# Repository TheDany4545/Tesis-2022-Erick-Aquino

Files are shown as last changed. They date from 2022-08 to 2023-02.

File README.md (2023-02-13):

# Estimulador nervio vago y su varilla programadora 2022
En este respositorio se encuentra la combinación de los avances previos a la Fase IV. En esta fase se logró crear un modo de reconocimiento automático. Además de la creación de PCB para la varilla programadora.

## Modo automático
Es basado en el modo de funcionamiento de *detección y respuesta* también conocido como *AutoStim* de los modelos LivaNova 106 y 1000. Consiste en emplear un sistema de monitoreo y recolección de información de impulsos eléctricos de la actividad cardíaca mediante un electrocardiograma (ECG). La administración de la dosis para la terapia se activa de forma automática al momento de detectar un aumento rápido en la frecuencia cardíaca, la cual es asociada a las convulsiones.

<p align="center">
  
</p>

### Documentación
Se encuentran artículos cientificos, datasheets de distintos componentes y microcontroladores, pinouts y base de datos en formato .csv para hacer las pruebas.

### Estimulador
Carpeta donde se encuentra los códigos de los microcontroladores ESP8266 y Trinket M0 para la estimulación VNS y la recepción de parámetros. También se encuntran los diseños de PCB's de distintos años.

### Recursos
Carpeta donde se encuentra la librería PyHRV modificada para la obtención de resultados en el análisis de los ECG´s. También se encuentra una herramienta de Matlab obtenida desde Physionet para la simulación de un ECG donde uno pude modificar parámetros de simulación. Se agregó un archivo .txt con un link para descargar todas las librerias y se describe la instalación en anaconda.

### Varilla Programadora
En la varilla programadora se tiene el envio de parámetros el cual es modificable a través de una interfaz gráfica la cual se ejecuta desde python y esto lo hace a través del microcontrolador ESP8266 al cual se le carga un programa en C que permite la comunicación entre la interfaz gráfica y el estimualdor por medio del envio de parámetros a través del NRFL24L01.

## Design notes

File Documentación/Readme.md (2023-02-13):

## Artículo científico
Artículo científico del cual se basó para la obtención de features de un electrocardiograma con enfoque a convulsiones en orden de poder predecir una convulsión antes de que ocurra con dichos features.

## Base de datos
Base de datos de electrocardiogramas haciendo actividad física a 500 Hz, sin filtrar.

## Esquemáticos
En esta carpeta se encuentran los Pinouts de los microcontroladores ESP8266, Trinket M0.

## Esquemas Fritzing
En esta carpeta se encuentran las conexiones de como es el cableado de Raspberry Pi4 con TTL, cableado de ESP8266 con NRF24L01 y pantalla LCD y cableado de Trinket M0 con NRF24L01. Todos los circuitos mencionados cableados en una simulación en el programa Fritzing.

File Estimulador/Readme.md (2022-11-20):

## Estimulador VNS
### Codigos microcontroladores
En esta carpeta se encuentra los códigos para usar con Trinket M0 y ESP8266. El trinket M0 conectado al NRFL24L01 tiene comunicación con el otro NRFL24L01 conectado al ESP8266, de esta manera se puede enviar y recibir los parámetros de estimulación.
### PCB´s
En esta carperta se encuentran archivos de texto con links para los distintos PCB´s de distintos años. Estos links son de google drive, se descargan los archivos y se abren con Altium Designer. La versión utilizada de Altium Designer es 19.0.15.

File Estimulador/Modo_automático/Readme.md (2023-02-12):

## Send_data
Programa para enviar por medio de comunicación serial el archivo de ECG seleccionado.
### Enable ttS0
Linea de código para ser ejecutada en CMD de RaspBerry Pi4 para habilitar puerto serial.

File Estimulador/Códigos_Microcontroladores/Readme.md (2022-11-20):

## Códigos para envio y recepción de parámetros
### Trinket M0
En esta carpeta se encuentra el código para recibir parámetros con el trinket M0 conectado a un NRF24L01. Se abre con ide de arduino.
### Estimulador_final
En esta carpeta se encuentra el código para enviar parámetros a través de ESP8266 conectado a un NRF24L01. Se abre con ide de arduino.

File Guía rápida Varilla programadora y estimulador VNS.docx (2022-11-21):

# Guía rápida Varilla programadora y estimulador VNS

## Instalación de librerías para enviroment de anaconda

- Instale Python 3.X
- Después de descargar anaconda se debe crear un enviroment nuevo como se muestra en al Figura No.1

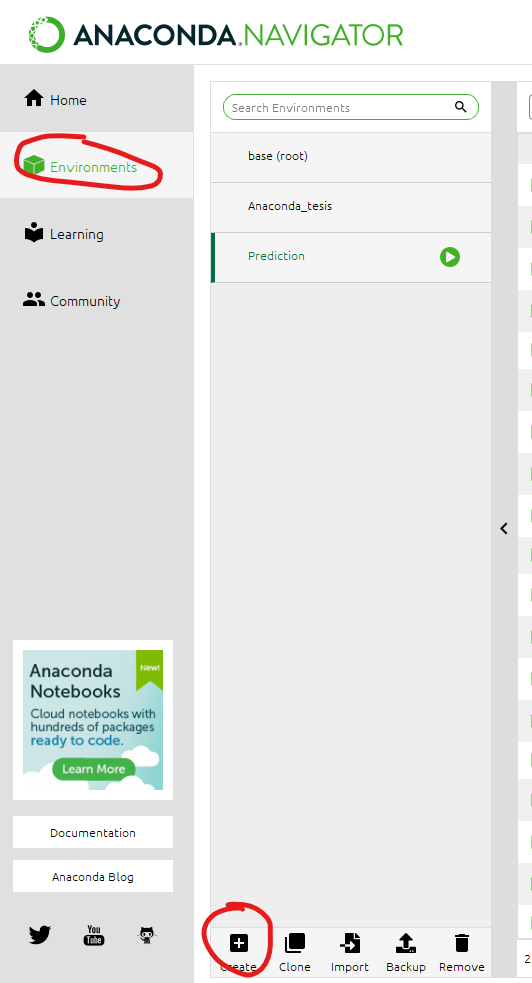
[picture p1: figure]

Figura No.1 – Creación de un nuevo enviroment

- Se instala spyder en el enviroment creado
- Para instalar el paquete de librerías “PyHRV” el cual da más conflictos es necesario seguir los siguientes pasos.
  - Desde el cmd ejecutar el siguiente comando “pip install pyhrv”
  - Si tiene error en la instalación con la librería specturm haga lo siguiente: Busque en su navegador Unofficial Windows Binaries for Python Extension Packages y busque el archivo. whl de spectrum. Descarguelo, si no encuentra uno, puede probar con el que se usó para resolver este problema (link (https://drive.google.com/file/d/1RalWyMJzHLhGzzO3uuIBB_u6xB2uzpj_/view?usp=share_link)).
  - Una vez descargado este archivo ejecute el comando “pip install path_del_archivo_whl”
  - Luego diríjase a la página oficial de Pyhrv (link (https://pypi.org/project/pyhrv/)) y desargue el archivo .whl para Python 3 o py3 como se ve en la figura No.2   Figura No.2 – archivo de Pyhrv.whl

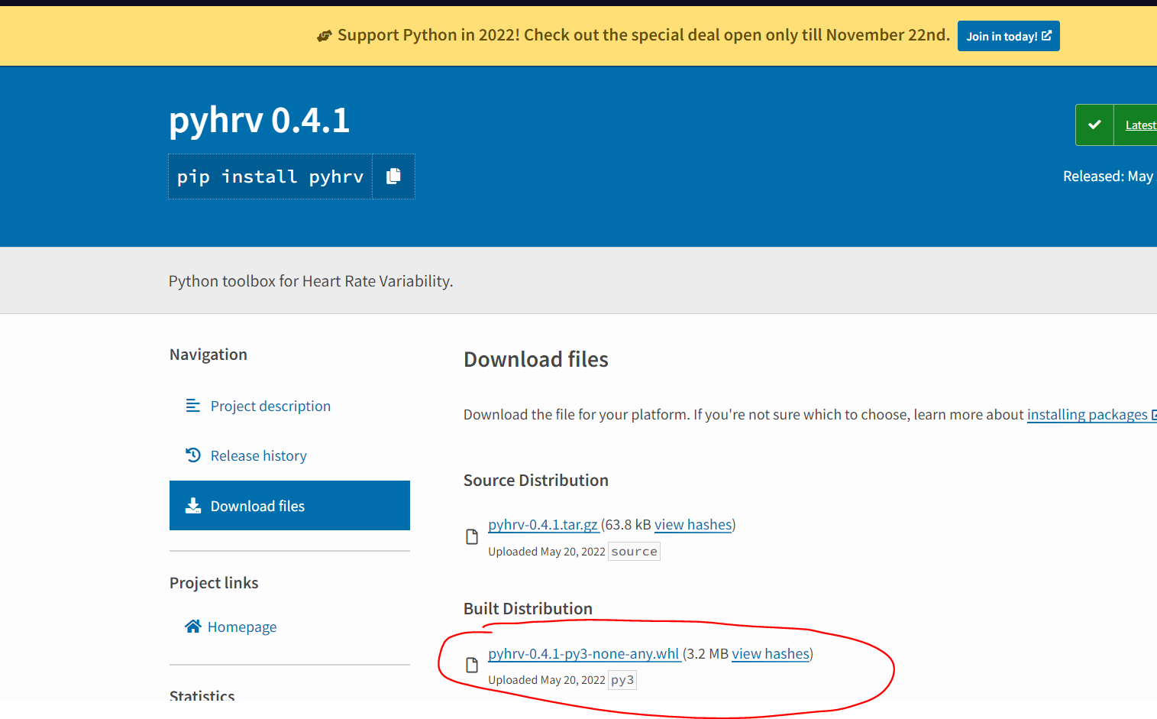
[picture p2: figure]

  - Una vez descargado desde el cmd ejecute el siguiente comando “pip install install path_del_archivo_whl ”
  - Puede probar con la versión utilizada para esta fase en el siguiente enlace (link (https://drive.google.com/file/d/1hLOSCwM4K9Iysz15rCaWuRM_AKxwgxKs/view?usp=share_link)).
  - Luego de haber instalado pyhrv traslade el conjunto de librerías instaladas hacia el enviroment de anaconda.
  - Para esto vaya a la ubicación de Python, ya en la carpeta busque la carpeta que se llame Lib>site-packages y luego copie las librerías instaladas. En mi caso la ruta es la siguiente: “C:\Users\eaqui\AppData\Local\Programs\Python\Python310\Lib\site-packages”
  - Luego de copiarlas diríjase a la la ubicación de Anaconda, ya en la ubicación dirigase a “envs>nombre_de_su_enviroment>Lib>site-packages” y pegue en esta ubicación las librerías. En mi caso esta ruta es “C:\Users\eaqui\.conda\envs\Prediction\Lib\site-packages”
- En caso de que no haya funcionado descargue directamente mi carpeta de “site-pacakges” que se encuentra en Google drive (link (https://drive.google.com/file/d/1yRFfxajOZiTD5mbhZKM890OWoaXSG9Wl/view?usp=share_link)) y reemplaze la carpeta por la que tiene en el directorio de anaconda “envs>nombre_de_su_enviroment>Lib>site-packages”.
- Ahora puede abrir anaconda en su enviroment y ejecute Spyder, abra el archivo llamado “ECG_Poincare.py”.
- Antes de ejecutar el archivo dirigase a PYTHONPATH manager y agrege un nuevo path como se muestra en la Figura No.3

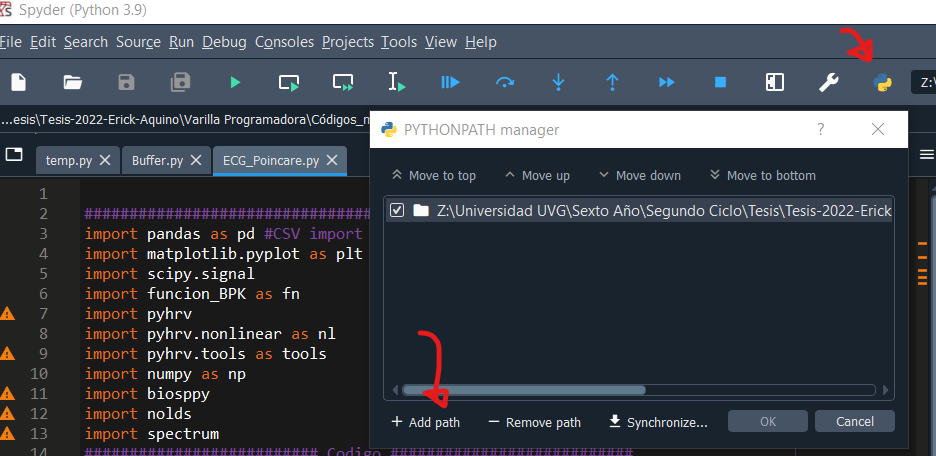
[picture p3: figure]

Figura No.3 – PYTHONPATH manager

- Busque la carpeta donde se encuentre el archivo “funcion_BPK.py” y agregue el path.
- En tools>preferences>IpyrhonConsole>Graphics>Backend seleccione QT5, como se muestra en la Figura No.4

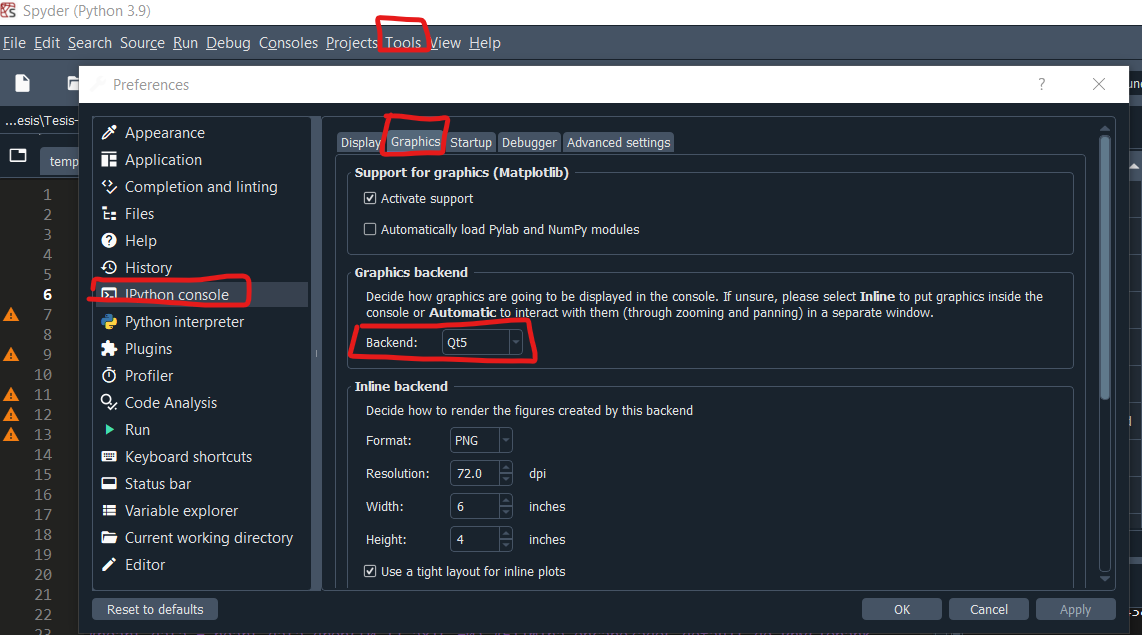
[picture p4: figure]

Figura No.4 – Configuración para poder ver mejor las gráficas

- Una vez agregado el path y configurado el apartado de las graficas, en el script solo asegúrese de que en la variable path tenga la ubicación de un ECG en formato .csv y ejecute el script. Deberá mostrarle una serie de graficas como se muestra a continuación en la Figura No.5.

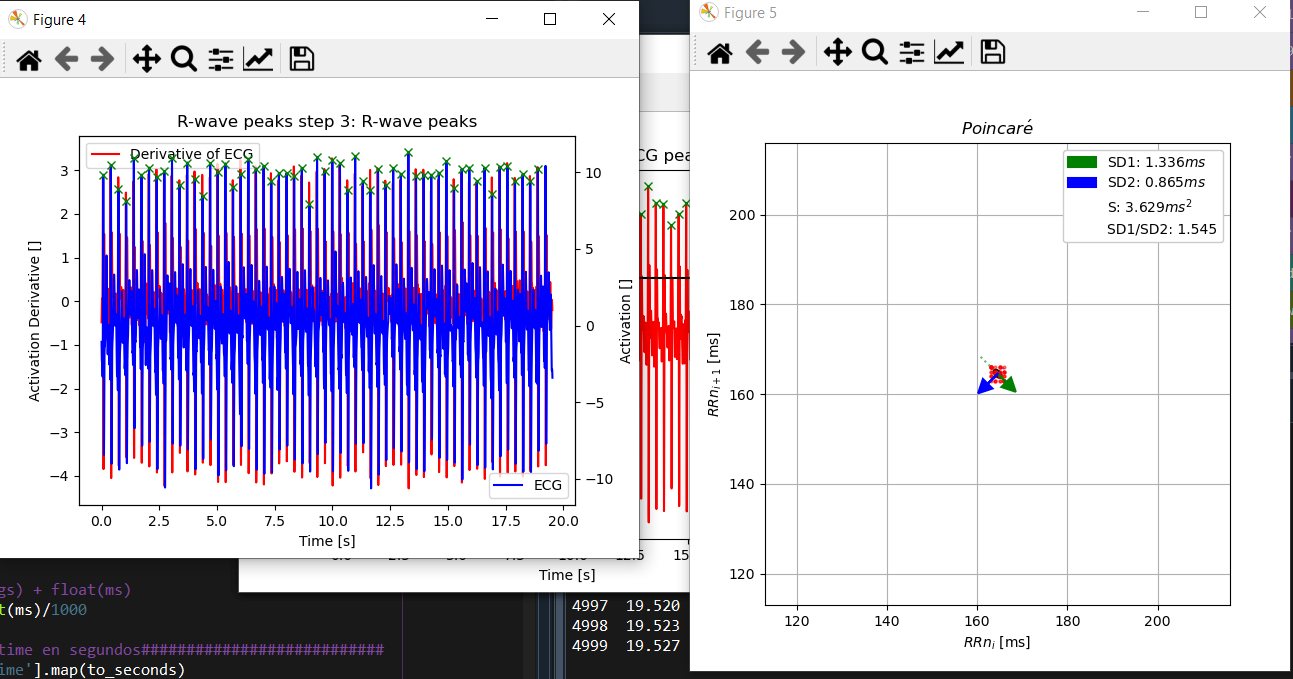
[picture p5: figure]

Figura No.5 – Gráficas resultantes

- Si ya corre tiene todo bien instalado en el apartado de la varilla programadora.

## Instalación de librerías para Arduino Trinket M0

- Instale Arduino IDE de su pagina oficial. La versión utilizada en esta fase es 1.8.13
- Para la instalación de las librerías de Trinket M0, diríjase al IDE de Arduino y File>Prefrences>Additional Boards Manager y coloque “https://adafruit.github.io/arduino-board-index/package_adafruit_index.json” como se muestra en la Figura No.6.

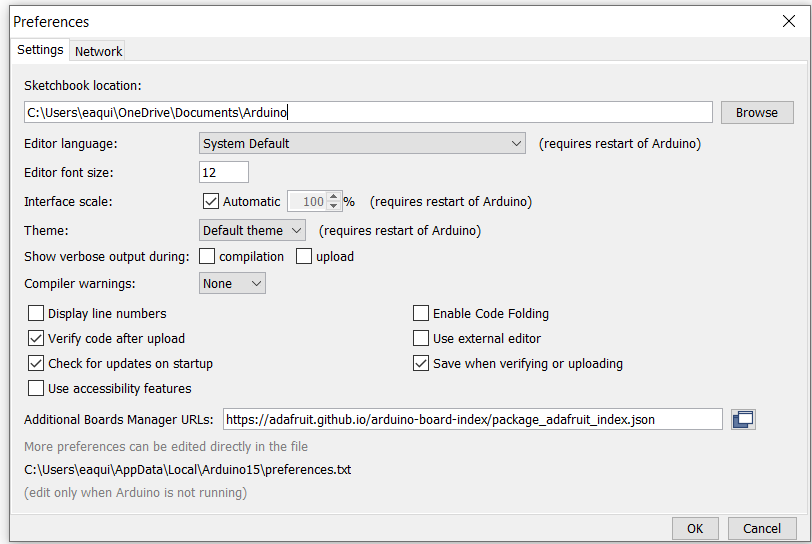
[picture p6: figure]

Figura No.6 – Arduino IDE, instalación de Trinket M0

  - Diríjase en el Arduino IDE hacia Tools>board>Boards Manager, busque e instale “Adafruit SAMD” como se muestra en la figura No.7

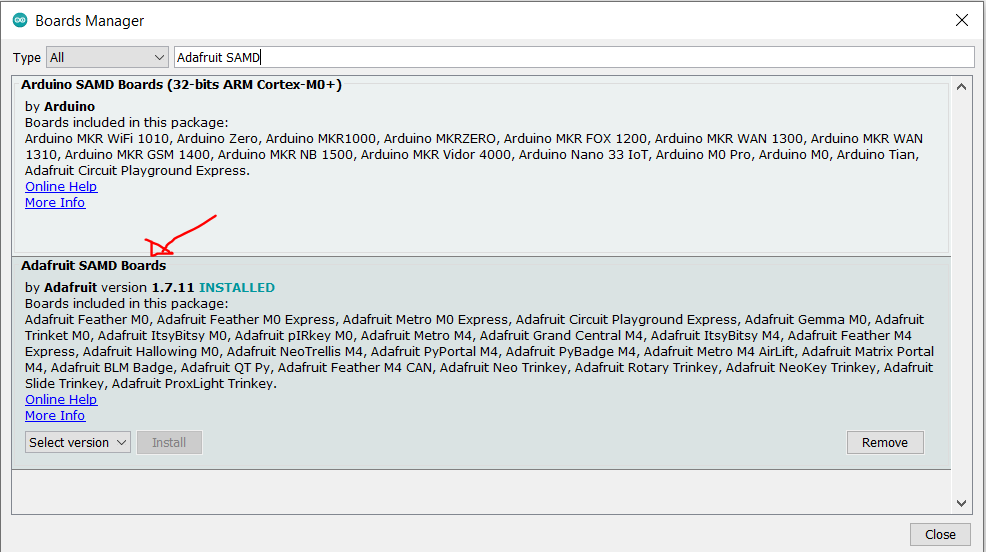
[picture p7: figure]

Figura No.7 – Board Manager instalación de Adafruit SAMD Boards

## Instalación de librerías para Arduino ESP8266

- Para la instalación de las librerías de Trinket M0, diríjase al IDE de Arduino en File>Prefrences>Additional Boards Manager y coloque seguido de una coma “http://arduino.esp8266.com/stable/package_esp8266com_index.json”, como se muestra en la Figura No.8.

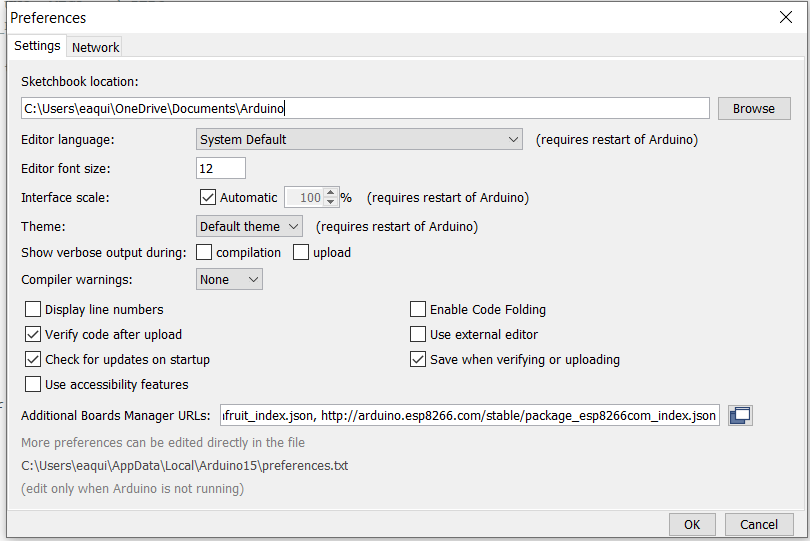
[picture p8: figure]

Figura No.8 - Arduino IDE, instalación de ESP8266

- Diríjase en el Arduino IDE hacia Tools>board>Boards Manager, busque e instale “ESP8266” como se muestra en la figura No.9

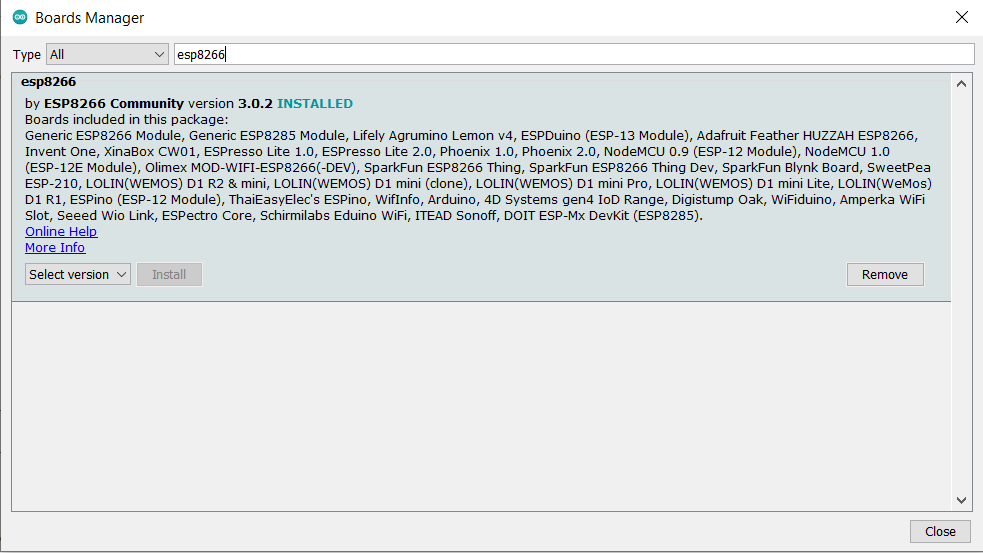
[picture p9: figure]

Figura No.9 - Board Manager instalación de ESP8266

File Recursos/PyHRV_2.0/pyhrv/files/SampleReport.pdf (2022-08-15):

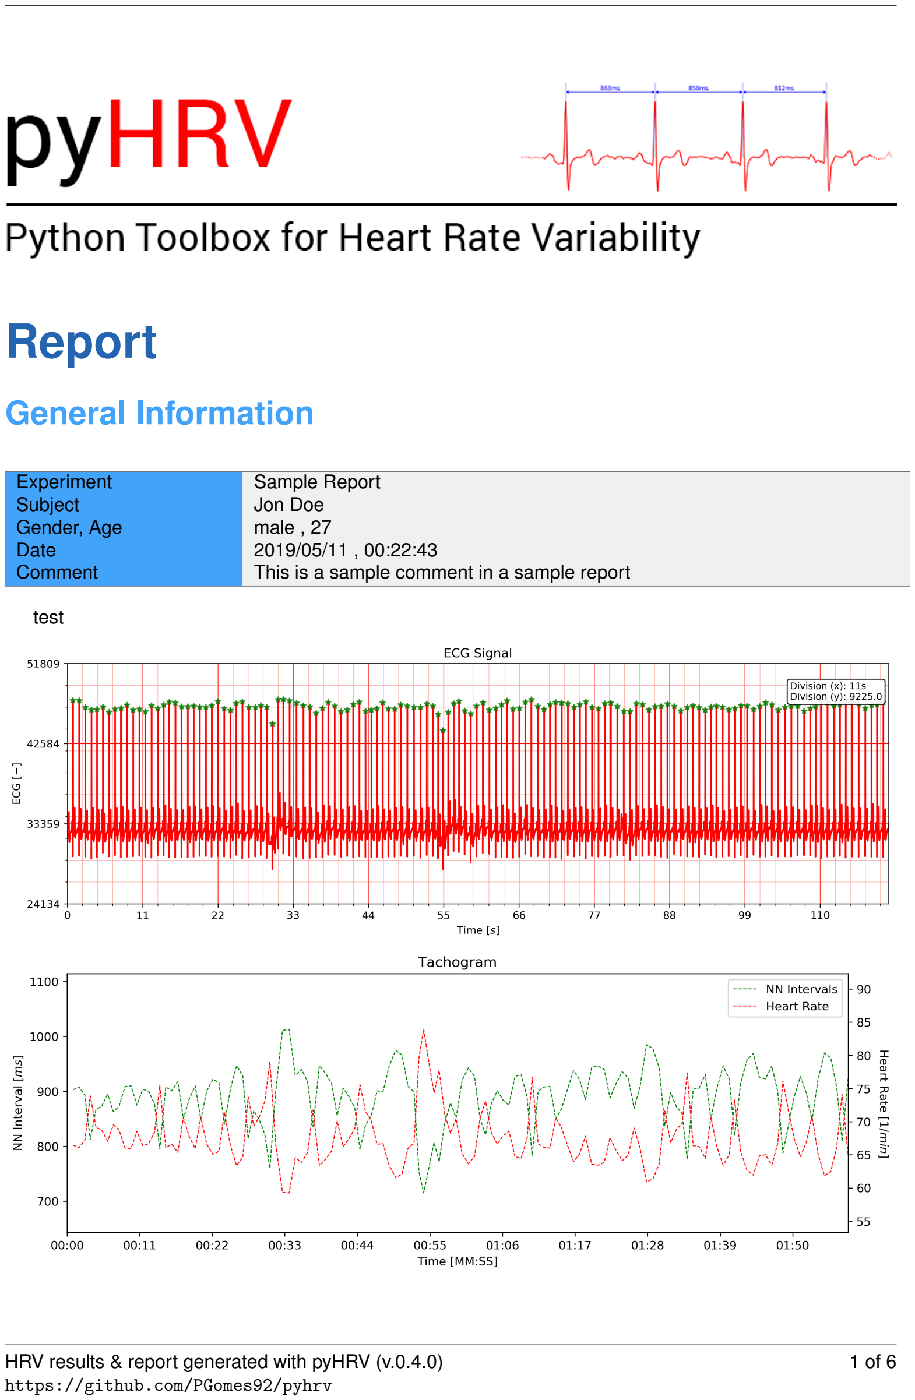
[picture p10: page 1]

# Report

# General Information

Experiment | Sample Report
Subject | Jon Doe
Gender, Age | male , 27
Date | 2019/05/11 , 00:22:43
Comment | This is a sample comment in a sample report

test

HRV results & report generated with pyHRV (v.0.4.0) https://github.com/PGomes92/pyhrv

pyHRV Report | Jon Doe, male, 27, 2019/05/11 00:22:43

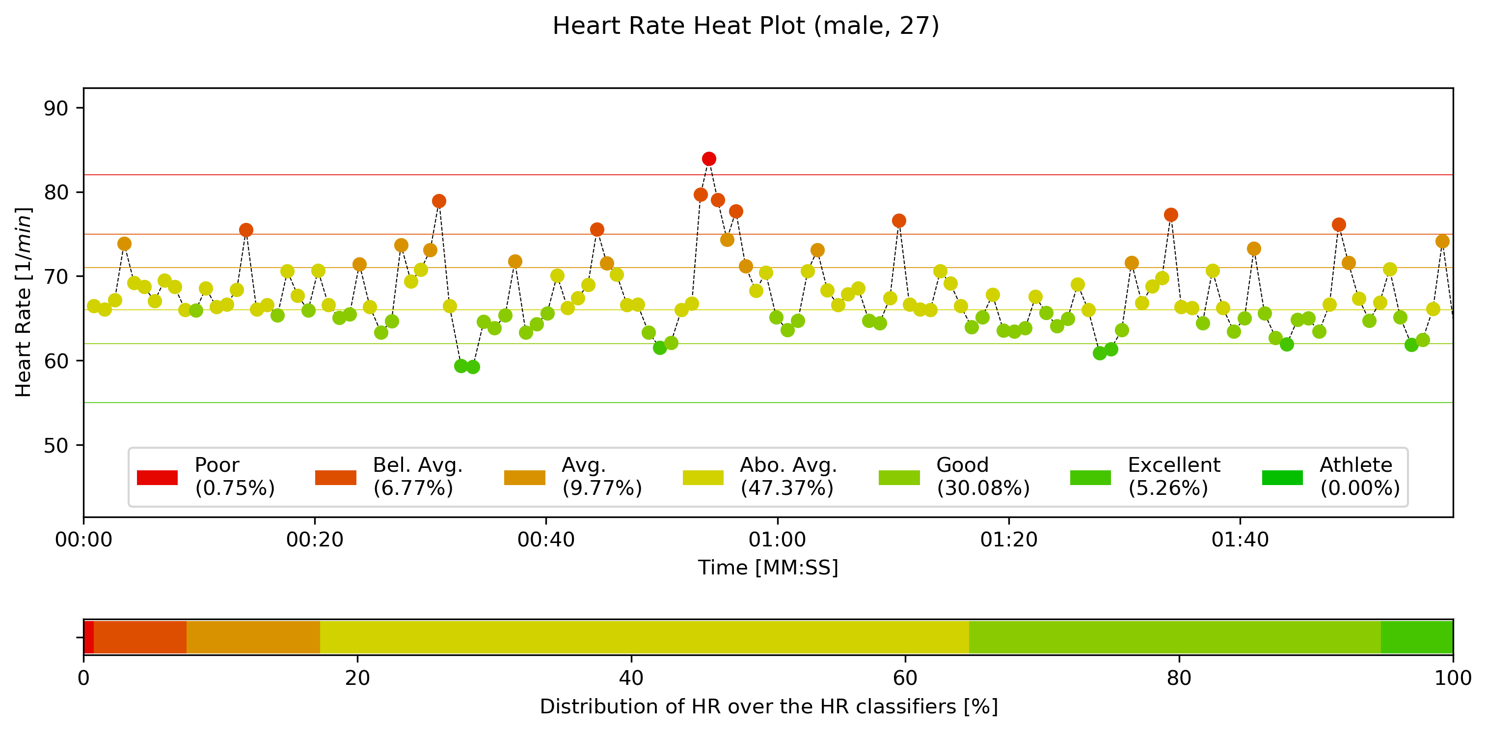
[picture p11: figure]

# Time Domain Results

Parameter | Value | Unit | Parameter | Value | Unit
NNI Parameters
NNI | 133 | - | NNI | 890.293 | ms
NNImin | 715.000 | ms | NNImax | 1013.000 | ms
SDNN | 53.571 | ms | RMSSD | 55.484 | ms
SDANN | nan | ms | SDNNindex | nan | ms
NN20 | 94 | - | pNN20 | 71.212 | -
NN50 | 47 | - | pNN50 | 35.606 | -
NNI Differences Parameters
∆NNI | 44.068 | ms | ∆NNImin | 1 | ms
∆NNImax | 146 | ms | SDSD | 33.840 | ms
HR Parameters
HR | 67.649 | bpm | HRmin | 59.230 | bpm
HRmax | 83.916 | bpm | σ(HR) | 4.295 | bpm
Geometrical Parameters
Triangular Index | 7.389 | ms | TINN | n/a¹ | -

1TINN function is not working properly in the current pyHRV version and computes incorrect results, reason for which it is not shown in this report

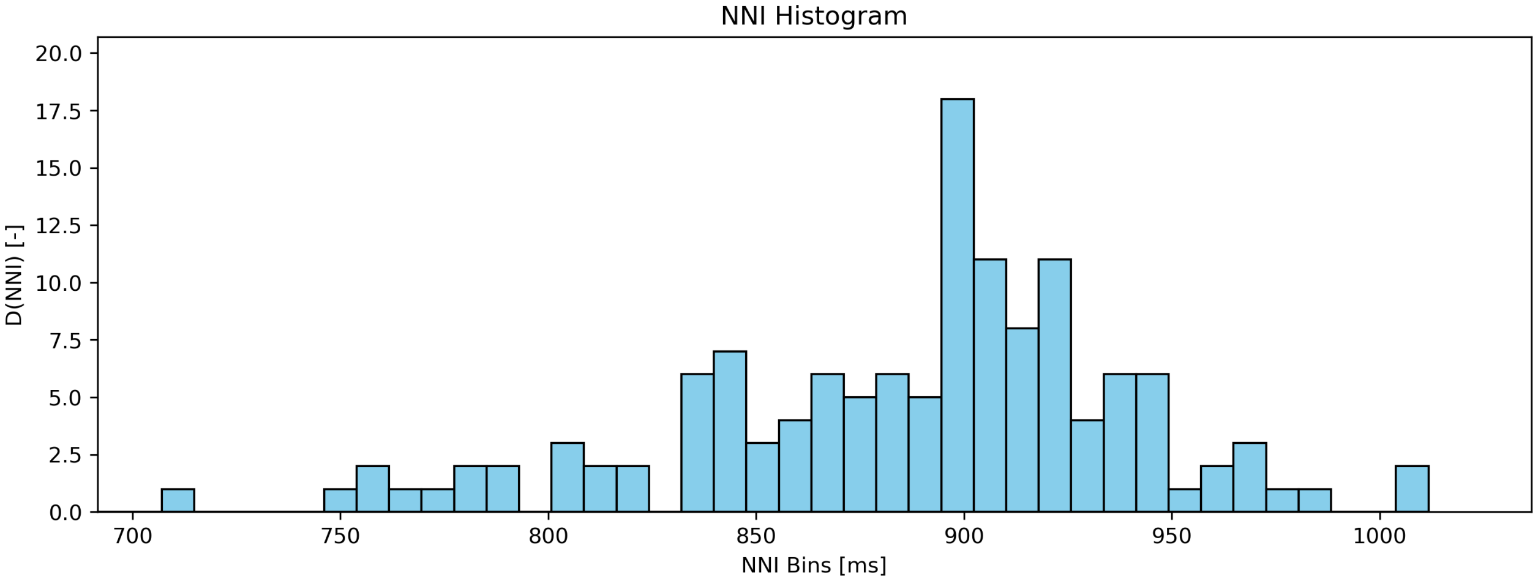
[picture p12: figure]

Figure 1: Histogram of the NNI series.

# Frequency Domain Parameters

Welch’s Method
| Unit | ULF | VLF | LF | HF
Peak Frequencies | Hz | n/a | 0.020 | 0.109 | 0.257
Absolute Powers | ms² | n/a | 424.130 | 1908.205 | 847.511
Relative Powers | % | n/a | 13.338 | 60.009 | 26.653
Logarithmic Powers | − | n/a | 6.050 | 7.554 | 6.742
Relative Powers | − | - | - | 60.009 | 26.653
LF/HF Ratio | − | 2.252
Total Power | ms² | 3179.846
Configuration: | Resampling frequency: | 4Hz | Window: | hamming
| Interpolation: | cubic | NFFT (over entire signal): | 4096

Autoregressive Method
| Unit | ULF | VLF | LF | HF
Peak Frequencies | Hz | n/a | 0.000 | 0.040 | 0.150
Absolute Powers | ms² | n/a | 2623.036 | 5480.309 | 10278.245
Relative Powers | % | n/a | 14.270 | 29.814 | 55.916
Logarithmic Powers | − | n/a | 7.872 | 8.609 | 9.238
Relative Powers | − | - | - | 29.814 | 55.916
LF/HF Ratio | − | 0.533
Total Power | ms² | 18381.590
Configuration: | Model Order: | 16 | NFFT (over entire signal): | 4096

Lomb-Scargle Method
| Unit | ULF | VLF | LF | HF
Peak Frequencies | Hz | n/a | 0.003 | 0.080 | 0.351
Absolute Powers | ms² | n/a | 432.338 | 2032.171 | 4068.332
Relative Powers | % | n/a | 6.618 | 31.107 | 62.275
Logarithmic Powers | − | n/a | 6.069 | 7.617 | 8.311
Relative Powers | − | - | - | 31.107 | 62.275
LF/HF Ratio | − | 0.500
Total Power | ms² | 6532.842
Configuration: | Moving Average Window Size: | n/a | NFFT (over entire signal): | 256

Selected Frequency Bands
ULF Band | Hz | 0 - 0
VLF Band | Hz | 0.000 - 0.040
LF Band | Hz | 0.040 - 0.150
HF Band | Hz | 0.150 - 0.400

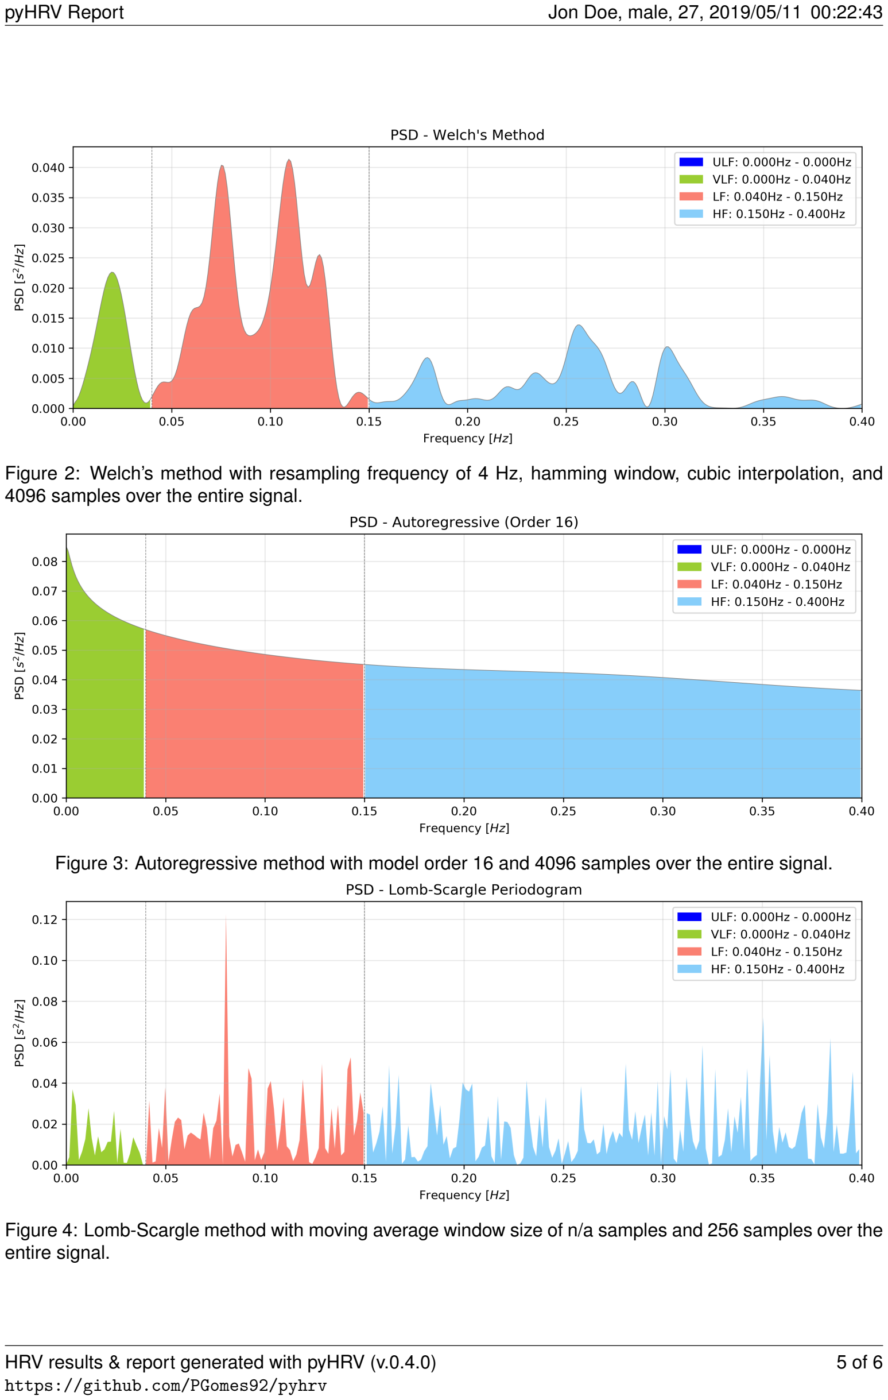
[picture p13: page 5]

Figure 2: Welch’s method with resampling frequency of 4 Hz, hamming window, cubic interpolation, and 4096 samples over the entire signal.

Figure 3: Autoregressive method with model order 16 and 4096 samples over the entire signal.

Figure 4: Lomb-Scargle method with moving average window size of n/a samples and 256 samples over the entire signal.

# Nonlinear Parameters

Parameter | Value | Unit | Parameter | Value | Unit
Poincare Plot Parameters ´
SD1 | n/a | ms | SD2 | n/a | ms
SD1/SD2 | n/a | ms | Ellipse Area S | n/a | ms

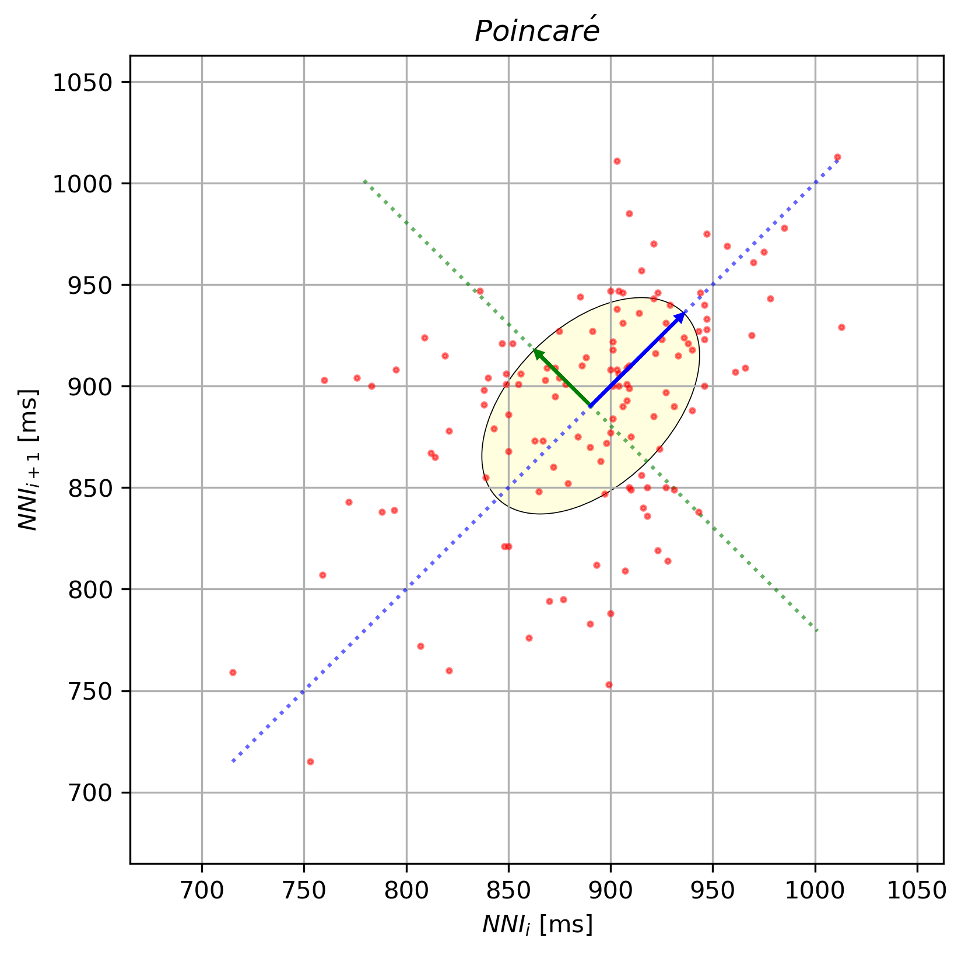
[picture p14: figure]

Glossary

AR | Autoregressive
BPM | Beats per Minute
DFA | Detrended Fluctuation Analysis
HF | High Frequency Band
HR | Hear Rate
LF | Low Frequency Band
∆NNI | Differences between successive NNI
NNI | Normal-to-Normal Intervals
NNx | # of ∆NNI ¿ x ms
pNNx | NNx / # of NNI
PSD | Power Spectral Density
RMSSD | Root Mean of Squared ∆NNI
SDANN | Standard Deviation of the Mean of NNI in all 5 minute Segments
SDNN | Standard Deviation of NNI
SDNNindex | Standard Deviation of the Mean of NN Intervals in all 5 minut Segments
SDSD | Standard Deviation of ∆NNI
TINN | Triangular Interpolation of the NNI Histogram
ULF | Ultra Low Frequency Band
VLF | Very Low Frequency Band

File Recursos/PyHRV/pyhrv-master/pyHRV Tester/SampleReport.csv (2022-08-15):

# BIOSPPY HRV REPORT - v.0.4.0
# File ; n/a
# Device ; n/a
# Identifier/MAC ; n/a
# Sampling Rate ; n/a
# Resolution ; n/a
# Date Time ; 2022-05-15_07-34-10
----------------------------------------------------------------------
COMMENTS
n/a
----------------------------------------------------------------------
NN INTERVALS (ms) ; n/a
----------------------------------------------------------------------
Time Domain
----------------------------------------------------------------------
Number of NNIs (-) ; 4684.000
Mean NNI (ms) ; 768.438
Minimum NNI (ms) ; 562.000
Maximum NNI (ms) ; 1188.000
Mean Delta-NNI (ms) ; 42.199
Minimum Delta-NNI (ms) ; 0.000
Maximum Delta-NNI (ms) ; 360.000
Mean Heart Rate (bpm) ; 78.990
Minimum Heart Rate (bpm) ; 50.505
Maximum Heart Rate (bpm) ; 106.762
Standard Deviation of Heart Rate (bpm) ; 8.305
SDNN (ms) ; 85.357
SDNN Index (ms) ; 82.555
SDANN (ms) ; 21.466
SDSD (ms) ; 43.391
RMSSD (ms) ; 60.523
NN50 (-) ; 1338.000
pNN50 (%) ; 28.571
NN20 (-) ; 3008.000
pNN20 (%) ; 64.232
Triangular Index (-) ; 11.509
TINN (ms) ; 0.000
TINN N (ms) ; 0.000
TINN M (ms) ; 0.000
----------------------------------------------------------------------
Frequency Domain - FFT Welch's Method
----------------------------------------------------------------------
Frequency Bands (Hz) ;
 | - | None
 | - | (0.0, 0.04)
 | - | (0.04, 0.15)
 | - | (0.15, 0.4)
Peak Frequencies (Hz) ;
 | - | 0.0185546875
 | - | 0.0400390625
 | - | 0.150390625
Absolute Powers (Hz) ;
 | - | 2050.743568530359
 | - | 2942.5372448423686
 | - | 1648.0967694750873
Logarithmic Powers (Hz) ;
 | - | 7.625957722723052
 | - | 7.987027496604833
 | - | 7.407376428087183
Relative Powers (%) ;
 | - | 30.878286062618393
 | - | 44.306127879882
 | - | 24.815586057499615
Normalized Powers (-) ;
 | - | 64.09871132538694
 | - | 35.901288674613056
Total Power (ms^2) ; 6641.378
LF/HF Ratio (-) ; 1.785
Number of PSD Samples (-) ; 4096.000
Window Function (-) ; hamming
Resampling Frequency (Hz) ; 4.000
Interpolation Method (-) ; cubic
----------------------------------------------------------------------
Frequency Domain - Autoregression Method
----------------------------------------------------------------------
Frequency Bands (Hz) ;
 | - | None
 | - | (0.0, 0.04)
 | - | (0.04, 0.15)
 | - | (0.15, 0.4)
Peak Frequencies (Hz) ;
 | - | 0.0
 | - | 0.0400390625
 | - | 0.150390625
Absolute Powers (ms^2) ;
 | - | 2299.9750620827376
 | - | 4846.798577513951
 | - | 9466.764350262958
Logarithmic Powers (Hz) ;
 | - | 7.740653559285737
 | - | 8.486073678867589
 | - | 9.155542454117699
Relative Powers (%) ;
 | - | 13.843981116403778
 | - | 29.173789354635215
 | - | 56.98222952896101
Normalized Powers (-) ;
 | - | 33.86158011090482
 | - | 66.13841988909519
Total Power (ms^2) ; 16613.538
LF/HF Ratio (-) ; 0.512
Number of PSD Samples (-) ; 4096.000
AR Order (-) ; 16.000
----------------------------------------------------------------------
Frequency Domain - Lomb-Scargle Method
----------------------------------------------------------------------
Frequency Bands (Hz) ;
 | - | None
 | - | (0.0, 0.04)
 | - | (0.04, 0.15)
 | - | (0.15, 0.4)
Peak frequencies (Hz) ;
 | - | 0.02250980392156863
 | - | 0.04341176470588235
 | - | 0.2347450980392157
Absolute powers (Hz) ;
 | - | 15.065218289462216
 | - | 46.19183177960316
 | - | 114.84694635936958
Logarithmic powers (Hz) ;
 | - | 2.712388662318789
 | - | 3.8328029811492086
 | - | 4.743600340704751
Relative powers (%) ;
 | - | 8.554728225934618
 | - | 26.22986003521764
 | - | 65.21541173884773
Normalized powers (-) ;
 | - | 28.683670053520075
 | - | 71.31632994647991
Total power (ms^2) ; 176.104
LF/HF ratio (-) ; 0.402
Number of PSD Samples (-) ; 256.000
Moving Average Window Size (-) ; n/a
----------------------------------------------------------------------
Nonlinear Methods
----------------------------------------------------------------------
SD1 (ms) ; 42.797
SD2 (ms) ; 112.837
SD2/SD1 (-) ; 2.637
Ellipse Area S (ms^2) ; 15170.898
Sample Entropy (-) ; 1.250
DFA alpha 1 (long term fluctuation) (-) ; 1.197
DFA alpha 1 beats range (-) ;
 | - | 4
 | - | 5
 | - | 6
 | - | 7
 | - | 8
 | - | 9
 | - | 10
 | - | 11
 | - | 12
 | - | 13
 | - | 14
 | - | 15
 | - | 16
DFA alpha 2 (long term fluctuation) (-) ; 0.882
DFA alpha 2 beats range (-) ;
 | - | 17
 | - | 18
 | - | 19
 | - | 20
 | - | 21
 | - | 22
 | - | 23
 | - | 24
 | - | 25
 | - | 26
 | - | 27
 | - | 28
 | - | 29
 | - | 30
 | - | 31
 | - | 32
 | - | 33
 | - | 34
 | - | 35
 | - | 36
 | - | 37
 | - | 38
 | - | 39
 | - | 40
 | - | 41
 | - | 42
 | - | 43
 | - | 44
 | - | 45
 | - | 46
 | - | 47
 | - | 48
 | - | 49
 | - | 50
 | - | 51
 | - | 52
 | - | 53
 | - | 54
 | - | 55
 | - | 56
 | - | 57
 | - | 58
 | - | 59
 | - | 60
 | - | 61
 | - | 62
 | - | 63
 | - | 64
None (None) ; n/a
None (None) ; n/a

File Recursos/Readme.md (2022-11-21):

## PyHRV_2.0
Libreria de Python modificada para obtener los features de los electrocardiogramas y el diagrama de poincaré.
## Matlab
Carpeta con un script de Matlab para la simulación de un electrocardiograma. Obtenido de Physionet.
## Avances primer ciclo
Carpeta dedicada a los archivos creado para presentar avances de Diseño e innovación de ingenieria I.
## Librerias Anaconda
En este archivo se encuentra un link para descargar todas librerias que se usó con anaconda, se agregan en la seguiente ruta "Anacnoda>Env>lib>site-packages". Se pegan en esa carpeta y se puede utilzar el enviroment de su preferencia.

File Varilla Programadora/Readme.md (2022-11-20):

## Varilla Programadora
### Códigos Microcontroladores
En esta carpeta se encuentra el código para enviar parámetros a través del ESP8266 y para modificar los parámetros se requiere de una interfaz gráfica la cual se hace desde python, por lo que se compone de dos programas uno en el lenguaje de programación que va compilado en el ESP8266 y el otro es ejecutado desde Python para la interfaz gráfica. Se recomiennda trabajar con Spyder.
### Códigos Modo Automático
Se encuntran los codigos en python que van integrados al envió de parametros. En estos códigos se hacen pruebas de como filtrar un ECG, envio y recepción de parametros a traves de comunicación serial simulando la lectura de un sensor, método diferencial de rítmo cardíaco para la detección automatica y un modelo entrenado de machine learning.

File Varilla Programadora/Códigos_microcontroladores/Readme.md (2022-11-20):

## Códigos para envio, recepeción de parámetros e interfaz gráfica

### Varilla_ESP
En esta carpeta se encuentra el código para enviar parámetros a través de ESP8266 conectado a un NRF24L01. Se abre con ide de arduino.
### Python_Varilla
En esta carpeta se encuentra el código para abrir la interfaz gráfica, con la interfaz gráfica se pueden seleccionar los parámetros a enviar. Se puede abrir solo con ide de Python, pero se recomienda usar Spyder.

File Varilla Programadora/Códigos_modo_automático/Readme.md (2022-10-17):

## ECG
Base de datos en formato .csv obtenido de la Physionet. Son electrocardiogramas tomados a 500 Hz de personas en reposo y haciendo actividad física.
## Python ECG
Programación en Python para filtrado de electrocardiogramas, obtención de features, método método diferencial de frecuencia cardíaca o HR-Diff por su nombre en inglés *heart rate differential method* y el modelo de machine learning para reconocer entre dos estados.

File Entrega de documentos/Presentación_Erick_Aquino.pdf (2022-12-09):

# Caracterización y validación de un Prototipo de Estimulador del Nervio Vago y su Varilla de Programación Inalámbrica para el Tratamiento de Epilepsia Fármaco Resistente - Fase IV

# ERICK DANIEL AQUINO PAZ

17319

# INGENIERÍA MECATRÓNICA UNIVERSIDAD DEL VALLE DE GUATEMALA

# RESUMEN

# El presente trabajo muestra la creación un modo de funcionamiento automático replicando el funcionamiento del modelo comercial AspireSR 106 de la empresa LivaNova. También la caracterización y validación el modulo de estimulación de

nervio vago y su varilla programadora.

# El modo automático es capaz de diferenciar dos estados de actividad física de las

personas por medio de lectura y análisis en tiempo real de electrocardiogramas,

# siendo capaz de enviar una señal para activar la estimulación del nervio vago

cuando se detecte cierto estado de actividad física.

# Se caracteriza y valida el envió y recepción de parámetros de la varilla programadora y se caracteriza los tiempos de envió de datos como el consumo

eléctrico.

# OBJETIVO GENERAL

# - Caracterizar y validar los módulos de la estimulación del nervio vago y varilla programadora desarrollados en la fase anterior del proyecto, y agregar un

modo de operación automático.

# OBJETIVOS ESPECÍFICOS

# - Desarrollar un protocolo de experimentos para evaluar más extensamente el consumo energético y el funcionamiento en general del sistema desarrollado

previamente.

# - Caracterizar el sistema por medio de los datos recopilados en los

experimentos de evaluación.

# - Desarrollar un modo de operación automático para el módulo de

estimulación.

# INTRODUCCIÓN

# Enfermedad Una de las enfermedades

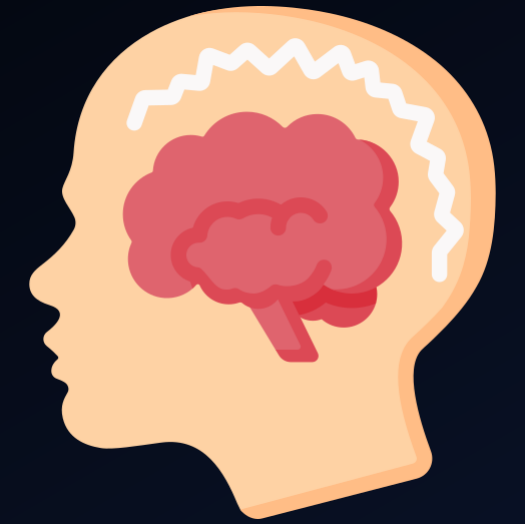
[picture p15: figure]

# neurológicas más comunes del mundo

# Tratamientos Fármacos antiepilépticos que eliminan completamente las convulsiones o ayudan a que

desaparezcan con el tiempo.

# Epilepsia refractaria Condición congénita que limita la efectividad de los fármacos antiepilépticos o desarrollan resistencia a los mismo a medida

que la epilepsia cambia.

# Síntomas Convulsiones, movimientos rápidos del cuerpo, perdida del conocimiento

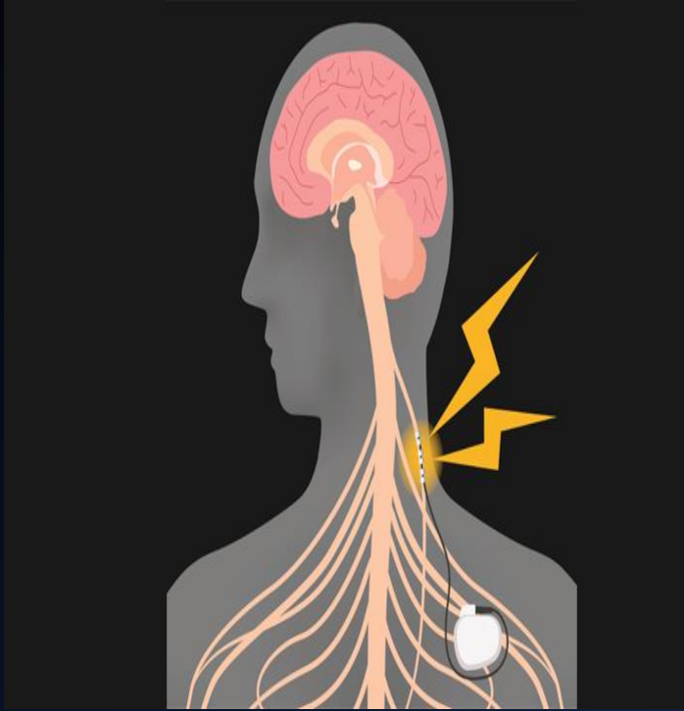
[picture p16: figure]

# Dispositivos neuromoduladores

Funcionamiento | Costos

# Pulsos eléctricos controlados

# Hasta $20,000 Cirugía y dispositivo

# LivaNova

# - Empresa global líder de tecnología médica en soluciones de neuromodulación. Dueña de productos neuromoduladores de más

altos estándares.

# Modelo AspireSR 106

Productos | Procedimiento | Dispositivo

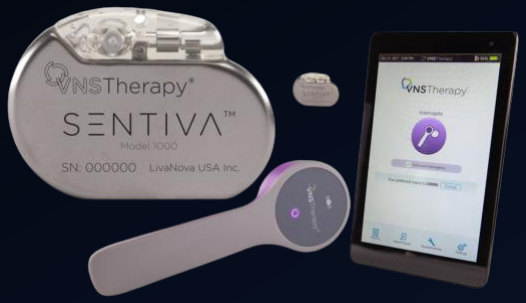
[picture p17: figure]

# ANTECEDENTES

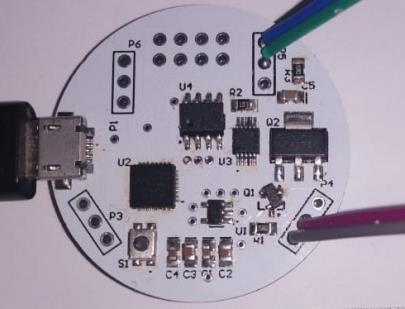
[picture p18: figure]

# Estimulador nervio vago

# - Señal de neuroestimulación

# - Alimentación del estimulador

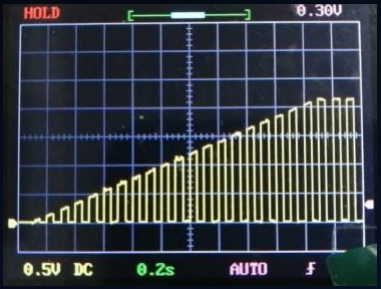
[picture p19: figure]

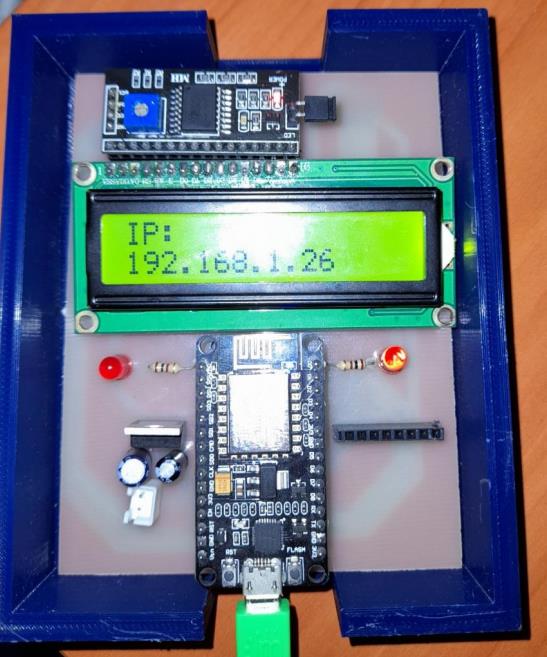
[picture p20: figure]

# ANTECEDENTES

# Varilla programadora

# - Conectividad por medio de comunicación serial o conexión wifi

# - Interfaz gráfica y sus

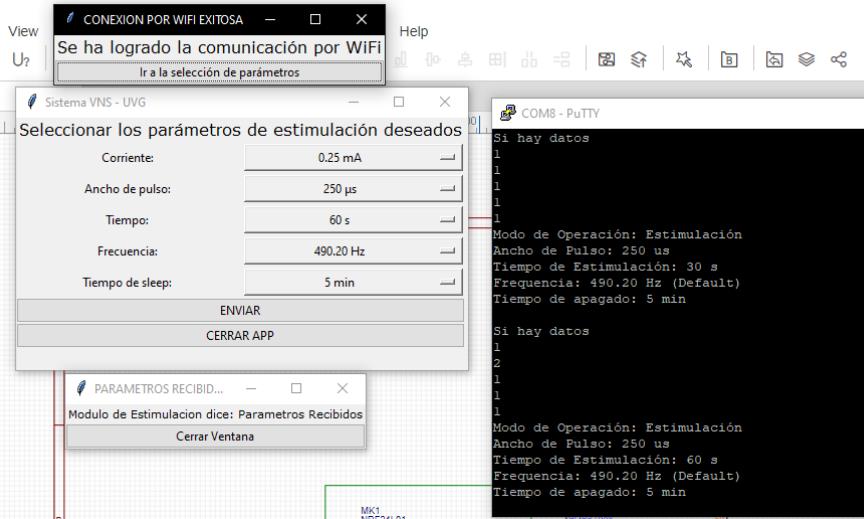
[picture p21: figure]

# parámetros

# METODOLOGIA

1

# - Análisis de funcionamiento de prototipos previos - Análisis del funcionamiento detección automática

2

# - Desarrollo de software filtrado de señales ECG - Desarrollo de software de detección de picos R

3

# - Análisis de señales ECG para extracción de características - Implementación de modelo de aprendizaje automático

4

# - Soldadura de estimulador de nervio vago - Validar y caracterizar funcionamiento de estimulador y su varilla programadora

# FASES DEL PROYECTO

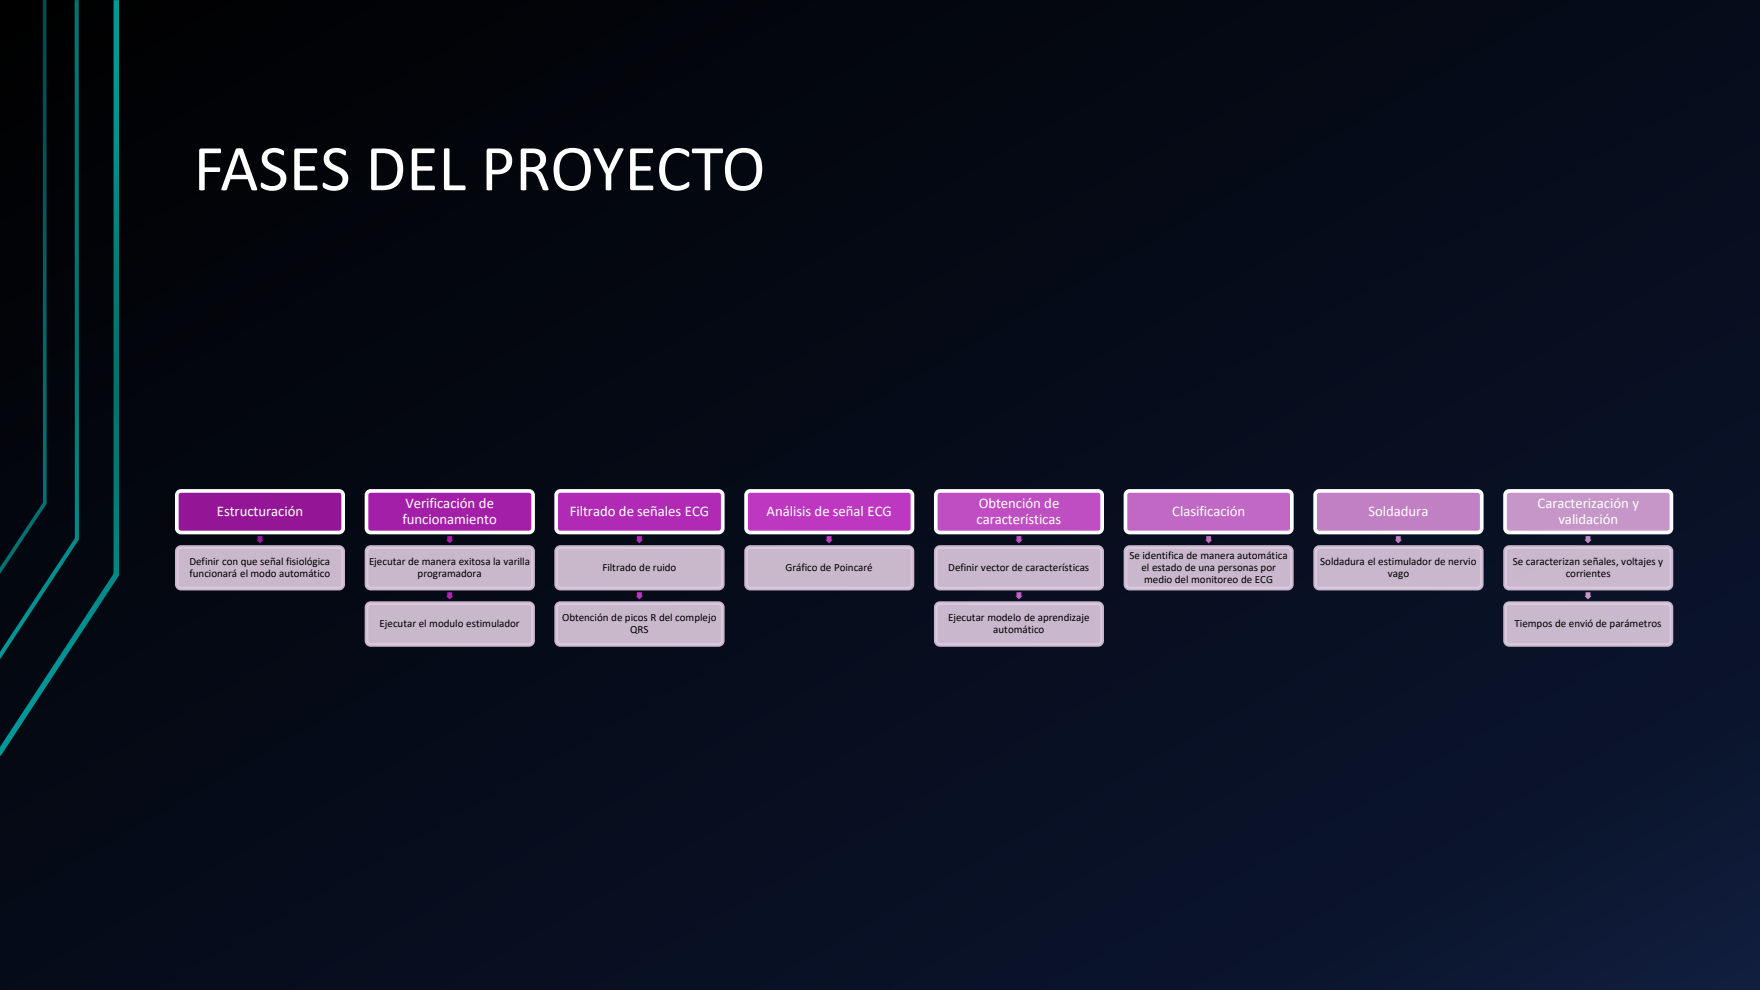
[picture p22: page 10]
Estructuración; Verificación de funcionamiento; programadora; QRS; Obtención de características; automático; Clasificación; Soldadura; vago; Caracterización y validación; corrientes

Filtrado de señales ECG

Análisis de señal ECG

Definir con que señal fisiológica
funcionará el modo automático

Ejecutar de manera exitosa la varilla

Filtrado de ruido

Gráfico de Poincaré

Definir vector de características

Se identifica de manera automática
el estado de una personas por
medio del monitoreo de ECG

Soldadura el estimulador de nervio

Se caracterizan señales, voltajes y

Ejecutar el modulo estimulador

Obtención de picos R del complejo

Ejecutar modelo de aprendizaje

Tiempos de envió de parámetros

# Diseño experimental

# Simulador de ECG

# RASPBERRYPI + USB A TTL

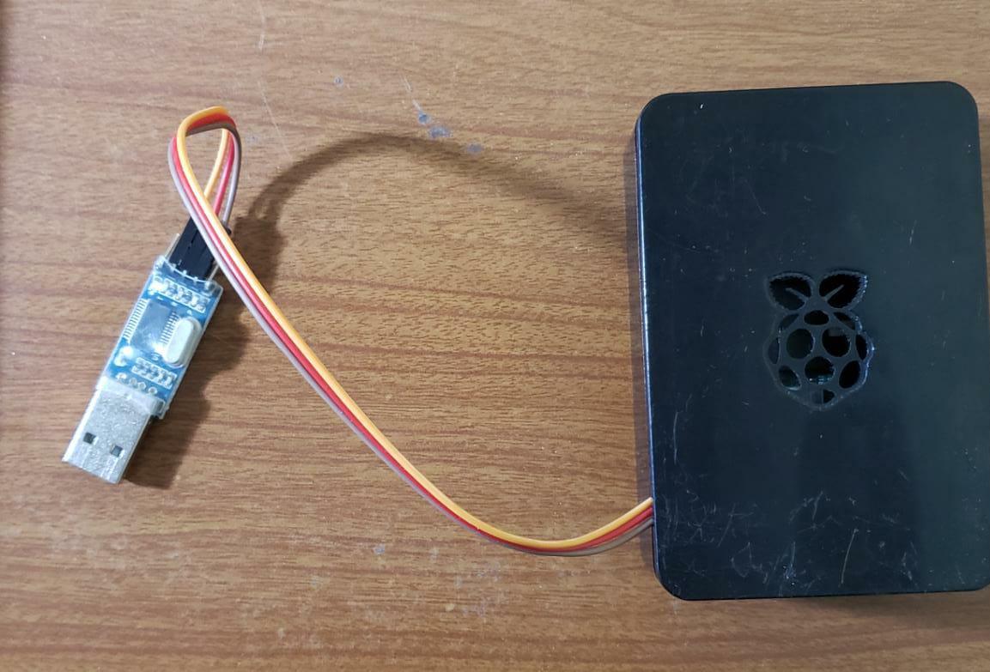
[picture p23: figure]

# - Lee y envía los datos obtenidos de señal ECG en tiempo real

# - Se simula enviando los datos a través de comunicación serial

por medio de una Raspberrypi.

# - Formato CSV

# Filtrado de ruido en señal ECG

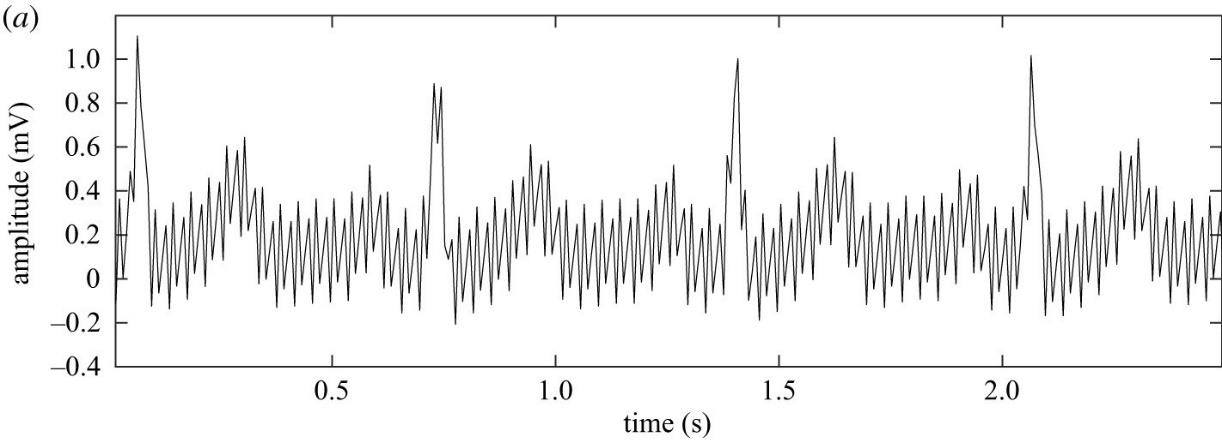
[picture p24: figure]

# - Distintas fuentes de ruido - Características perdidas durante el filtrado - Filtro Butterworth de

# 55Hz a 60 Hz


# Detección de picos R

# - Complejo QRS - Picos R - Derivada de la señal ECG


# - Obtención de picos R

# Análisis de señales fisiológicas

# - Análisis en el dominio del tiempo

# - Análisis en el dominio de la frecuencia


# - Análisis no lineales


# Gráfico de Poincaré

Experimental | Teórico


# Algoritmo para la clasificación de latidos del corazón

# - Método diferencial de frecuencia cardiaca

# Obtención de vector de características

# - Combinación entre gráfico de Poincaré y el método diferencial de frecuencia


# cardiaca obtenemos las

características deseadas.

# - Se ha demostrado que mediante este método se puede detectar un suceso de 60 segs a 20 segs antes de que

suceda.

# Aprendizaje automático

# - Regresión logística presentó mejores resultados


# - Se logra clasificar con un 93% de precisión entre estado en reposo y estado de actividad

física.


# COMUNICACIÓN RF ENTRE TRINKET M0 Y ESP8266

# Previamente solo se había logrado con éxito la comunicación RF entre Arduino y ESP8266

# Soldadura módulo estimulador


# - Soldadura por medio de pistola de calor

# - Soldadura con horno

# RESULTADOS

# - Obtención de características de un ECG por medio de algoritmo de

clasificación del ritmo cardiaco y análisis de gráfico de Poincaré.


# Resultados

# RESULTADOS

# - Clasificación entre estado en reposo y estado de


# actividad física, por medio

de aprendizaje automático.

# - La clasificación tiene una

precisión del 93%.

# Señal PWM del modulo estimulador

# Comunicación RF e Interfaz gráfica


# CONCLUSIONES

# - Se logró el sistema de operación automático para la detección de

estados de una persona.

# - Se validó el funcionamiento de la interfaz gráfica de la varilla

programadora.

# - Se validó el funcionamiento de la pantalla LCD para brindar el código a

ingresar en la interfaz gráfica de la varilla programadora.

# - Se logró la clasificación de señales ECG por medio de técnicas de

aprendizaje automático.
- Se validó la comunicación RF entre ES8266 y Trinket M0, consecuentemente el envió y recepción de parámetros de ambas vías.

# RECOMENDACIONES

# - Se recomienda buscar nuevas características para una mejor

asertividad en el aprendizaje automático.

# - Se recomienda desarrollar un dispositivo que funcione como bootloader para la programación de ATSAMD21E18 y de esta

manera sacrificar Trinket M0 para la programación del mismo.

# - Se recomienda la fabricación de nuevas placas para el estimulador

del nervio vago.

# - Se recomienda verificar el funcionamiento de todas las partes por

separado y luego proceder a probarlas en conjunto.

# REFERENCIAS BIBLIOGRÁFICAS

- Livanova VNS Una Introducción a VNS Therapy, sep. de 2018. dirección: https : / / www . livanova . com / epilepsy - vnstherapy / getmedia / 6fd40c67 - 3089 - 4a2b - b41a-9f3f2b3dd3cc/introduction-to-vns-therapy-spanish.pdf.
- AspireSR All the benefits of previous generations of VNS Therapy. dirección: https: //epilepsyswo.ca/wp-content/uploads/2019/05/AspireSRFAQ.pdf.
- Epilepsia: MedlinePlus enciclopedia médica, es. dirección: https : / / medlineplus . gov/spanish/ency/article/000694.htm (visitado 09-05-2022).
- R. J. Figueroa, “Integración y Mejora de un Prototipo de Estimulador del Nervio Vago y su Varilla de Programación Inalámbrica para el Tratamiento de Epilepsia Fármaco Resistente - Fase III,” 2022.
- E. Task Force of the European Society of Cardiology the North American Society of Pacing, “Heart Rate Variability,” Circulation, vol. 93, n.o 5, págs. 1043-1065, mar. de 1996, Publisher: American Heart Association. doi: 10 . 1161 / 01 . CIR . 93 . 5 . 1043. dirección: https://www.ahajournals.org/doi/full/10.1161/01.cir.93.5.1043 (visitado 02-12-2022).
- S. K. Ghatak y S. Aditya, Poincaré parameters and principal component analysis of Heart rate variability of subjects with health disorder, arXiv:1802.10289 [physics], feb. de 2018. dirección: http://arxiv.org/abs/1802.10289 (visitado 27-09-2022).
- J. Piskorski y P. Guzik, “Filtering Poincaré plots,” en, Publisher: ICHB PAS Poznan Supercomputing and Networking Center. doi: 10.12921/CMST.2005.11.01.39-48. dirección: http://www.cmst.eu/articles/filtering- poincare- plots (visitado 02-12-2022).
- J. Jeppesen, S. Beniczky, P. Johansen, P. Sidenius y A. Fuglsang-Frederiksen, “Detection of epileptic seizures with a modified heart rate variability algorithm based on Lorenz plot,” English, Seizure - European Journal of Epilepsy, vol. 24, págs. 1-7, ene. de 2015, Publisher: Elsevier, issn: 1059-1311, 1532-2688. doi: 10 . 1016 / j . seizure . 2014 . 11 .
004. dirección: https : / / www . seizure - journal . com / article / S1059 - 1311(14)00303-3/fulltext#relatedArticles (visitado 25-09-2022).
- Difference between RR interval and NN interval, en-US. dirección: https://hexoskin. zendesk . com / hc / en - us / articles / 360045123314 - Difference - between - RR -interval-and-NN-interval (visitado 30-11-2022).
- C. Cárdenas y J. Ancízar, “Eliminación de perturbaciones en señales ECG utilizando filtrado de Kalman implementado en un DSP,” spa, bachelorThesis, Pereira : Universidad Tecnológica de Pereira, dic. de 2014. dirección: http://repositorioslatinoamericanos. uchile.cl/handle/2250/141362 (visitado 22-11-2022).
- ECG interpretation: Characteristics of the normal ECG (P-wave, QRS complex, ST segment, T-wave), en-US. dirección: https://ecgwaves.com/topic/ecg-normal-pwave-qrs-complex-st-segment-t-wave-j-point/ (visitado 25-11-2022).
- H. H. P. Staff, Heart rate variability: How it might indicate well-being, en, nov. de 2017. dirección: https://www.health.harvard.edu/blog/heart- rate- variabilitynew-way-track-well-2017112212789 (visitado 30-11-2022).

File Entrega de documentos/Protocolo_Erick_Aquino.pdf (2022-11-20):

## UNIVERSIDAD DEL VALLE DE GUATEMALA Facultad de Ingeniería

Guatemala,

Caracterización y Validación de un Prototipo de Estimulador
del Nervio Vago y su Varilla de Programación Inalámbrica
para el Tratamiento de Epilepsia Fármaco Resistente - Fase IV

Protocolo de trabajo de graduación presentado por Erick Daniel Aquino

Paz, estudiante de Ingeniería Mecatrónica

## Resumen

Se pretende seguir mejorando el prototipo de VNS que se trabajó en la fase anterior, más extensamente en el consumo energético y funcionamiento general del sistema. También se busca caracterizar el sistema por medio de los datos recopilados y desarrollar un modo de operación automático para el módulo de estimulación. Esto con el fin de mejorar y estar cada vez más cerca de un equipo neuro estimulador que permita mejorar la calidad de vida de las personas que sufran de epilepsia fármaco resistente manteniendo un precio accesible. Para llevar a cabo esta serie de avances se probarán y evaluarán el consumo energético del módulo estimulador y de la varilla programadora. Para el desarrollo del modo de operación automático que se tomo de referencia del modelo comercial AspireSR 106 se tiene previsto el desarrollo por versiones de un programa que pueda cumplir con la función de detectar patrones.

## Antecedentes

La idea de tratar la epilepsia sin necesidad de fármacos antiepilépticos proviene de las personas que tienen una condición congénita que limita la efectividad de los fármacos o que desarrollan una resistencia a los mismos a medida que su epilepsia evoluciona. Es conocida como epilepsia refractaria/fármaco-resistente, para la cual la efectividad de los fármacos antiepilépticos resulta ser nula, debido a que existe una resistencia bio-química a los componentes de estos medicamentos que tratan de actuar sobre el sistema límbico y sistema nervioso.

Tratamiento VNS de LivaNova

Para tomar acción ante esta necesidad la empresa de servicios médicos LivaNova decidió lanzar un neuromodulador que busca abordar el problema de ataques epilépticos utilizando descargas eléctricas periódicas y controladas dirigidas al nervio vago. Este tipo de neuromodulación se conoce como Estimulación de Nervio Vago o Vagus Nerve Stimulation (VNS). Es una técnica de estimulación en la que consiste en provocar una serie de descargas periódicas y controladas al nervio vago con el fin de que estas descargas afecten las partes específicas del cerebro para combatir los síntomas que provocan las convulsiones. Este tratamiento por estumulación del nervio vago (VNS) también resultó ser muy útil, seguro y eficaz para niños, pues los niños con epilepsia tratados sólo con medicamentos pueden ver menguado su desarrollo. Además se han resgistrado mejoras en la lucidez, concentración y los niveles de energía [1]. La exposición de este tratamiento por largos periodos de tiempo demostró una reducción en la incidencia de ataques epilépticos en pacientes que padecen de epilepsia refractaria en un 81 %. También se reportó que dentro de este grupo de pacientes hubo un 12 % que dejaron de reportar convulsiones en un período de 10 meses bajo el tratamiento [2].


Figura 1: Estimulador y varilla programadora VNS [2].

VNS Pulse 102/102R-Aspire 106

LivaNova tiene una serie de estimuladores para el tratamiento por VNS. Debido a que se debe introducir el estimulador mediante de un procedimeinto quirúrgico ambulatorio es necesario que estos estimuladores cuenten con una aleación de titanio bio-compatible. Los estimuladores operan según una serie de parámetros previamente estudiados de la reacción del cuerpo humano ante los estímulos. El médico encargado sera quien determine los parámetros por medio de la varilla programadora. Los parámetros a variar mediante la varilla programadora son la frecuencia, amplitud y ciclo de trabajo del PWM que se utiliza para la estimulación del nervio vago. El modelo de estimulador de nervio vago LivaNova: VNS Pulse 102 cuenta con dos partes el estimulador el cual es ubicado dentro del paciente y la varilla programadora con la cual el médico ajusta los parámetros por paciente para un tratamiento adecuado. Este modelo LivaNova: VNS Pulse 102 fue presentado por Cybertronics en 1997 y aprobado por la FDA (Food and Drug Administration) en 1998, tiene 24 años desde que fue lanzado al mercado conviertinendolo en el modelo más antiguo y con más tiempo en el mercado [3].

Se toma como base el modelo LivaNova: VNS Pulse 102, aunque cuenta con un funcionalidad menos que el modelo AspireSR 106 esta ofrece una mejor versatilidad en cuanto a contrucción y la electrónica que posee, debido a que el precio de los componentes electrónicos con aplicaciones médicas representan una fracción del precio actual del tratamiento por estimulación de nervio vago de $20,000. Por lo que a partir de estas características se puede llegar a tener un dispositivo con una funcionalidad similar por una fracción del costo. La funcionalidad que ofrece el modelo AspireSR 106 consiste en un monitoreo al incremento de los latidos del corazón, el cual le llaman Detección y Respuesta. Este modo detecta un aumento rápido de la frecuencia cardíaca, que suele asociarse con el inicio de una crisis epiléptica. Al detectar este aumento en la frecuencia cardíaca se responde administrando una dosis adicional de la terapia [1]. Esto no implica que el paciente no puede hacer ejercicio pues la frecuencia cardíaca aumentará pero no hará ningun daño recibir una dosis extra del tratamiento durante el ejercicio [4].

Como se oberva en la Figura 2 se tiene el model AspireSR 106 el cual incluye la función de Detección y Respuesta, se aclara que al activar este modo la el tiempo de vida de la batería desciende considerablemente debido a que este siempre esta monitoreando la frecuencia


Figura 2: Estimulador modelo AspireSR 106 [4].

cardíaca [1].

Fases previas

En las fases previas se trabajó en la elaboración de un sistema de neuro modulación utilizando PWMs de amplitud variable. También se trabajó en hacer modificación en el PCB del módulo estimulador y en el PCB de la varilla programadora. Así mismo se trabajo en el diseño 3D de la varilla programadora. Todo esto se llevó a cabo durante las fases anteriores y en el trabajo previo que consistió en tres prototipos en los cuales se mejoraba funcionalidad y tamaño.

Estimulador nervio vago - fase previa

En la fase III del Estimulador del Nervio Vago trabajado por Rodrigo Figueroa [5] se logró mejorar la funcionalidad del prototipo del Estimulador del Nervio Vago que se desarrolló en la fase I y II con el fin de prepararlos para pruebas en tejido animal. Se desarrolló circuitos impresos las cuales tuvieron tres fases hasta alcanzar entra cada un un objetivo, se observan en las figuras 3,4,5. Se llegó a la implementación de componentes SMD en los circuitos impresos lo cual representa un gran avance para la reducción de tamaño. En la última fase se con la implementación de componentes SMD se logró implementar un módulo de conexión inalámbrica que permite la comunicación entre la varilla programadora y el estimulador. Se realizó una carcasa a la medida hecho de PLA, la cual encaja con la última versión de la varilla programadora. También se avanzó en una interfaz gráfica por medio de una pantala LCD en la cual se pueden ver los envios de parámetros por medio de la varilla programadora como se puede apreciar en la figura 6. También se empezó a investigar sobre materiales bio compatibles con el cuerpo humano para el encapsulamiento del Estimulador del Nervio Vago.

Alcance y limitaciones

Con lo que respecta a potabilidad esta es una de las mayores limitaciones para el módulo estimulador y la varilla programadora debido a que no cuenta con una fuente de energía independiente para poder usarla desconectada de una fuente de poder. Esto conlleva a que no se ha optimizado el consumo energético y eficiencia de la propuesta actual.


Figura 3: Estimulador versión 1 [5].


Figura 4: Varilla programadora versión 2 [5].

## Justificación

En la actualidad se estima que alrededor de 50 millones de personas que padecen de epilepsia lo que lo convierte en uno de los trastornos neurológicos más comunes que afecta a personas de todas las edades. Según las estimaciones, en todo el mundo se diagnostican unos 5 millones de casos de epilepsia. En los países de ingreso alto se estima que 49 de cada 100,000 personas son diagnosticadas de epilepsia cada año, mientras que en los países de ingresos medianos y bajos se estima que la cifra es de 139 de cada 100,000 personas. Cerca del 80 % de las personas con epilepsia viven en países de ingresos medianos y bajos. Se estima que en los países de ingresos medianos y bajos tres cuartas partes de la población que padecen de ataques epilépticos no reciben el tratamiento que necesitan [6] [7].

Estos hechos y cifras indican que se vive en una realidad donde muchas personas que sufren de ataques epilépticos no son capaces de costear un tratamiento, esto implica que su calidad de vida se vea afectada. El tener una condición en la que puede darse un episodio epiléptico


Figura 5: Estimulador versión 3 [5].


Figura 6: Varilla programadora versión 3 [5].

en cualquier momento y que muchas veces esta condición es incomprendida por el público en general, incluso pueden ser víctimas de la estigmatización y la discriminación reflejan la calidad de vida que puede llegar a tener una persona que no recibe el tratamiento que necesitan. Agregando a eso el 25 % de las personas con epilepsia lidian con epilepsia refractaria o también conocida como epilepsia fármaco resistente. Muchas de las personas que inician con algún tipo de epilepsia tratable, evolucionan a tener epilepsia fármaco resistente (EFR) [7].
En la búsqueda de una alternativa para el tratamiento fármaco-químico que busca limitar y controlar la actividad cerebral se desarrolló VNS, el cual busca reestructurar los patrones de descarga y funcionamiento del cerebro para tratar la causa de la epilepsia y detener los ataques de forma proactiva. También este tratamiento es recomendado para niños debido a que este no mengua su desarrollo y se han registrado mejoras en la lucidez, concentración y niveles de energía [1].
El pionero en el campo de terapia VNS es LivaNova quienes ofrecen el equipo que incluye una varilla programadora y el estimuladora que se acompaña junto a la cirugía de inserción por un precio que ronda alrededor de los $20,000 dependiendo del modelo del equipo. Es un tratamiento que en definitiva mejora la calidad de vida de las personas que pueden costearlo. Esto nos lleva a uno de los factores que limitan optar a este tratamiento, el factor económico pues en 80 % de los casos de epilepsia provienen de los países de ingresos medianos o pequeños, lo cual nos da un indicio que la mayoría de personas no pueden optar por el costo del equipo y el costo de las visitas al médico. Otro de los factores a tomar en cuenta es el desfase que existe de la tecnología, pues no hay suficientes médicos que conozcan de este tipo de alternativas, menos médicos certificados para realizar el procedimiento y los parámetros a usar el equipo.

Con los presentes hechos se comenzó el desarrollo de una alternativa costo eficiente para el modulo estimulador y programador de tratamiento VNS en la Universidad del Valle de Guatemala. En este desarrollo se toma como referencia el VNS pulse 102 de LivaNova. El proyecto se inicio en distintas fases, el objetivo a alcanzar es el desarrollar un dispositivo con funcionalidad comparable de dicha referencia por una fracción de su precio. De la fase pasada se hicieron mejoras en el diseño del circuito del estimulador de nervio vago. También se trabajó en la integración del módulo estimulador con la varilla programadora. Estos cambios realizados son cruciales para que la interacción de con ambos módulos del tratamiento VNS sean de manera fácil e intuitiva [5].
En la fase previa se realizaron avances para el módulo estimulador y para la varilla programadora. Se realizaron las pruebas y se verificó que todo funcionara según lo esperado. Sin embargo, no se logró cuantificar el consumo de ambos componentes en modo standby y en operación. Esto debe ser cuantificado para poder saber la potencia que se necesita para que el equipo funcione adecuadamente. Además, con el dato se puede saber si el prototipo ya es viable para el uso de baterías y hacer el modelo portable y funcional.
En la fase previa también se trabajó en la integración de un módulo de comunicación inalámbrica entre la varilla programadora y el estimulador. Se llevó a cabo una conexión entre ambas partes para el envío y recepción de datos. Por medio de la pantalla LCD se logra ver la dirección IP si la conexión fue exitosa y de lo contrario muestra error de conexión. Parte de las recomendaciones es mejorar la iconografía para una mejor estética y organización. También es posible mejorar la manera que uno se conecta al dispositivo, debido a que solo desde la programación se puede configurar para que se conecte a una sola dirección IP. Dentro de esta optimización se puede agregar el modo de operación automática la cual sería el de reconocer cuando se esta por tener un caso de epilepsia y se aplica una dosis de VNS automáticamente.
Debido a que el costo del tratamiento original es una barrera muy grande para que sea considerada una opción para muchas personas y más considerando que una gran mayoría de casos de epilepsia de da en los países menos desarrollados o de ingresos medianos y bajos. Se debe pensar que el tener acceso a tecnología de neuroestimulación por una fracción de su precio es algo que puede cambiarle la vida a las personas de tal manera que mejoraría su estilo de vida.

## Objetivos

Objetivo General

Caracterizar y validar los módulos de la estimulación del nervio vago y varilla programadora desarrollados en la fase anterior del proyecto, y agregar un modo de operación automático.

Objetivos Específicos

Desarrollar un protocolo de experimentos para evaluar más extensamente el consumo energético y el funcionamiento en general del sistema desarrollado previamente.

Caracterizar el sistema por medio de los datos recopilados en los experimentos de evaluación.

Desarrollar un modo de operación automático para el módulo de estimulación.

## Marco teórico

La epilepsia es un trastorno cerebral en el cual una persona tiene convulsiones repetidas durante un tiempo. Estas convulsiones se deben a una actividad cerebral anormal y descontrolada que deriva en la perdida de atención o de la conciencia a la persona que presente comportamientos anormales. La epilepsia es causada cuando los cambios en el tejido cerebral hacen que el cerebro este demasiado irritable o excitable. Debido a esto el cerebro envía señales de manera anormal, lo cual termina en convulsiones [8].

Una convulsión es una descarga excesiva y corta de la actividad cerebral eléctrica, esta causa que cambie como se siente, piensa y comporta una persona. No todas las convulsiones son causadas por epilepsia y una sola convulsión que no ocurre de nuevo no es epilepsia. Durante una convulsión epiléptica, el balance normal entre la estimulación e inhibición de la actividad cerebral se rompe. Comúnmente se le llama ataques o episodios, pero el termino correcto es convulsión [9].

El tratamiento más común para tratar la epilepsia es el farmacológico. La gran parte de las personas que padecen de epilepsia puede utilizar fármacos antiepilépticos (AEDs, Antiepileptic drugs) como forma de tratamiento. Es la forma de tratamiento más común, ayuda entre un 70-80 % de las personas a curarse completamente o a lograr que las convulsiones desaparezcan con el tiempo.

Dentro de los antiepilépticos más comunes:

Valproato de sodio

Carbamazepina

Lamotrigina

Topiramato

La población que queda libre de convulsiones epilépticas, un 80 % necesitará solo de un fármaco para el control y un 10-15 % necesitará una combinación de dos fármacos. El tipo de fármaco antiepiléptico a tomar dependerá de factores como el tipo de convulsión, edad, la respuesta del fármaco en el cuerpo del paciente entre otros. El objetivo de esta terapia con fármacos es controlar/ eliminar las convulsiones con un solo fármaco. Es necesario observar al paciente debido a que se pueden presentar rumores o defectos metabólicos al incrementar dosis o combinar fármacos [10].

Epilepsia refractaria farmacológica

Los fármacos antiepilépticos son esenciales para el tratamiento de la epilepsia. Sin embargo, existen pacientes en los que los fármacos no logran controlar las convulsiones con los dos primeros fármacos, incluyendo las combinaciones de estos dentro de 1-2 años de haber empezado el tratamiento. Estos pacientes que siguen sufriendo convulsiones después de muchas pruebas con AEDs, se consideran pacientes con epilepsia refractaria farmacológica [11].

El caso de los pacientes que padecen de la epilepsia refractaria farmacorresistente las opciones de tratamiento son muy limitadas. Esto resulta ser serio pues las crisis epilépticas evitan el desempeño funcional del individuo en cualquiera que sea su área de operación. Existen diversas explicaciones de por qué los múltiples y diferentes AEDs no funcionan en estos individuos, dichas explicaciones pueden definir en los diferentes tipos de refractariedad que desarrollan o presentan de manera congénita estos individuos [12].

Persistencia de crisis | Índice de Intratabilidad
Droga no de primera línea, sin importar su dosis | 0
Droga de primer línea con subdosificación | 1
Droga de primera línea con dosis adecuada | 2
Droga no de primera línea con rango sérico adecuado | 3
Droga no de primera línea con dosis máxima tolerable | 4
2 o más drogas de primer línea a dosis máximas tolerables | 5
2 o más drogas de primer línea a dosis máximas tolerable y droga de segunda línea | 6

Cuadro 1: Escala de de Schmidt [13].

Existen escalas como la Escala de Schmidt 1, la cual sirve para catalogar a la epilepsia de dos distintas maneras. Con un valor de (0-3) es una epilepsia no tratada de manera suficiente o refractariedad si esta en el rango de (4-6), todo depende de la persistencia de las crisis epilépticas basada en los fármacos utilizados. [13].

A pesar de que son más limitados los métodos para tratar la epilepsia farmacorresistente, existe otros métodos para tratarlos. Uno de estos métodos es con una cirugía de epilepsia, esta suele ser efectiva pero es la opción que más riesgo presenta, dado que es a cráneo abierto. Otro factor que limita a optar por esta cirugía es que el foco de las convulsiones debe estar en un lugar del cerebro en el que se puede remover sin impacto a las funciones de lenguaje y fuerza. Debido a este factor muy pocos pacientes son elegibles para la cirugía.

Otras opciones populares son los dispositivos de neuromodulación o neuroestimulación. Estas son el tratamiento por estimulación del nervio vago (VNS), neuroestimulación responsiva (RNS) y estimulación profunda cerebral (DBS) [14].

Existen diversas técnicas para reconocimiento de patrones, en el campo de la inteligencia artificial machine learning es una herramienta muy utilizada para el reconocimiento de patrones. Existen varios métodos en el reconocimiento de patrones por medio de machine learning uno de ellos es la comparación con un modelo. Esta al tener uno de los enfoques más simples debido a que es una operación genérica utilizada para la similitud entre dos entidades, estas pueden ser puntos, curvas, figuras del mismo tipo. Al tener esta versatilidad de poder comparar ya sea por puntos o curvas que ya han sido estudiadas 7, de esta manera se puede comparar para tener un reconocimiento con una precisión acertada.


Figura 7: Curva de un electrocardiograma antes de tener un ataque epiléptico [15].

## Metodología

En esta sección se describen los pasos se describen los pasos preliminares que se toman para el avance de las distintas fases del estimulador VNS y varilla programadora para poder garantizar un funcionamiento óptimo, esto incluye la simulación, así como la parte electrónica y la programación que conlleva.

Ensamble y pruebas de fase anterior

Hacer pruebas con el modulo estimulador donde se hicieron pruebas en una placa para un LM2622, donde se mejoró el diseño en el PCB para reducir inductancias parasitas y el manejo de corriente de manera eficiente. Así mismo se hacen pruebas con la varilla programadora ensamblando la carcasa la cual incluye la agarradera, tapadera inferior, el circuito y su tapadera superior.

Simulación del entorno

Es necesario recrear un pulso similar al patrón de una frecuencia cardíaca que se asocia a un ataque epiléptico. Esta simulación de pulsos servirá para entrenar el algoritmo de detección automática que estará en el modo automático del módulo estimulador VNS.

Desarrollo de software

Parte de lo previsto para el proyecto es desarrollar un modo de operación automático que permita al módulo de estimulación estimular el nervio vago al detectar la frecuencia cardíaca. Para esto se necesita de un algoritmo que reconozca el patrón del aumento de frecuencia cardíaca que va relacionada con ataques epilépticos, dejando una ventana para el aumento de frecuencia cardíaca cuando uno se ejercita.

Pruebas del circuito

Para optimizar el consumo energético actual primero se debe medir lo que se consume actualmente y encontrar en que tarea el consumo energético es más alto. Una vez encontrado se procede a buscar alternativas para un uso eficiente de la energía.

## Cronograma de actividades

Actividades | Julio 4 -8 | Julio 11 - 15 | Julio 18 - 22 | Julio 25 - 29 | Agosto 1 - 5 | Agosto 8 - 12 | Agosto 15 - 19 | Agosto 22 - 26 | Agosto 29 -
Septiembre 2 | Septiembre 5 - 9 | Septiembre 12 - 16 | Septiembre 19 - 23 | Septiembre 26 - 30

### 1 Requerimientos Preliminares

1.1 Pruebas con la varilla programadora 1.1.1 Pruebas con el estimulador
1.2 Poner a prueba LM2622
2 Simulación de entorno
2.1 Estdudiar ritmo cardiaco
2.1.1 Estudiar ritmo cardicaco al hacer deporte 2.3 Replicar frecuencias cardiacas
3 Desarrollo de Software
3.1 Estudiar machine learning
3.2 Técnicas de machine learning 3.3 Protitpo 1 del código
3.4 Protitpo 2 del código
3.5 Protitpo 3 del código
3.7 Pruebas reconocimiento patrones
3.6 Pruebas Estimulador a Varilla programadora 4 Pruebas del circuito
4.1 Probar el estimulador
4.2 Medición de consumo energético
4.3 Búsqueda de alterniativas
4.4 Probar PCB con modificaciones
4.5 Probar PCB con modificaciones versión 2 4.6 Probar PCB con modificaciones versión 3 5 Poner a prueba las partes trabajando
5.5 Implementación de todas los partes 5.6 Pruebas Finales
5.7 Entrega/ demostración de proyecto
Cronograma de Actividades | Universidad del Valle de Guatemala Dr. Luis Alberto Rivera
Erick Daniel Aquino Paz
Carnet: 17319
Diseño e innovación de ingeniería

## Índice preliminar

1. Prefacio
2. Lista de figuras
3. Lista de cuadros
4. Resumen
5. Abstract
6. Introducción
7. Antecedentes

7.1 Tratamiento VNS de LivaNova

7.2 VNS Pulse 102/102R-Aspire 106

7.3 Fase previa

7.4 Estimulador nervio vago - fase previa

8. Justificación
9. Objetivos

9.1 Objetivo General

9.2 Objetivos Específicos

10. Marco teórico
11. Alcance

11.1 Epilepsia refractaria farmacológica

12. Metodologia

12.1 Ensamble y pruebas de fase anterior

12.2 Simulación de entorno

12.2.1 Simulación versión 1
12.2.2 Simulación versión 2

12.3 Optimización de interfaz gráfica

12.4 Desarrollo de software

12.4.1 Desarrollo de software versión 1 12.4.2 Desarrollo de software versión 2

12.5 Cuantificar consumo en ambos módulos

12.6 Optimizar consumo energético

12.7 Pruebas del circuito

13. Diseño experimental

14. Resultados
15. Conclusiones
16. Recomendaciones
17. Bibliografía
18. Anexos

## Referencias

[1] Livanova VNS Una Introducción a VNS Therapy, sep. de 2018. dirección: https : / / www . livanova . com / epilepsy - vnstherapy / getmedia / 6fd40c67 - 3089 - 4a2b -b41a-9f3f2b3dd3cc/introduction-to-vns-therapy-spanish.pdf. (https://www.livanova.com/epilepsy-vnstherapy/getmedia/6fd40c67-3089-4a2b-b41a-9f3f2b3dd3cc/introduction-to-vns-therapy-spanish.pdf)
[2] “VNS Therapy System Epilepsy Physician’s Manual,” en Bioinspiration & biomimetics, 1.a ed., vol. 1, pág. 164.
[3] Summary of safety and effectiveness data (ssed). dirección: https://www.accessdata.fda.gov/cdrh_docs/pdf/p970003s207b.pdf. (https://www.accessdata.fda.gov/cdrh_docs/pdf/p970003s207b.pdf)
[4] AspireSR All the benefits of previous generations of VNS Therapy. dirección: https: //epilepsyswo.ca/wp-content/uploads/2019/05/AspireSRFAQ.pdf.
[5] R. J. Figueroa, “Integración y Mejora de un Prototipo de Estimulador del Nervio Vago y su Varilla de Programación Inalámbrica para el Tratamiento de Epilepsia Fármaco Resistente - Fase III,” 2022.
[6] The Epilepsy Foundation, en-US. dirección: https://epilepsychicago.org/ (visitado 01-05-2022).
[7] Epilepsia, es. dirección: https : / / www . who . int / es / news - room / fact - sheets / detail/epilepsy (https://www.who.int/es/news-room/fact-sheets/detail/epilepsy) (visitado 01-05-2022).
[8] Epilepsia: MedlinePlus enciclopedia médica, es. dirección: https : / / medlineplus . gov/spanish/ency/article/000694.htm (https://medlineplus.gov/spanish/ency/article/000694.htm) (visitado 09-05-2022).
[9] O. D. MD, Epilepsy: A Patient and Family Guide, en. Demos Medical Publishing, dic. de 2007, Google-Books-ID: YkZyDRl4mnUC, isbn: 978-1-934559-91-8.
[10] R. S. o. M. ( Britain), Journal of the Royal Society of Medicine, v. 84. Academic Press, 1991. dirección: https://books.google.com.gt/books?id=bnJRAQAAIAAJ.
[11] T. Yamamoto, “Recent Advancement of Technologies and the Transition to New Concepts in Epilepsy Surgery,” en, Neurologia medico-chirurgica, vol. 60, n.o 12, págs. 581-593, 2020, issn: 0470-8105, 1349-8029. doi: 10.2176/nmc.ra.2020-0197. (https://doi.org/10.2176/nmc.ra.2020-0197) dirección: https: //www.jstage.jst.go.jp/article/nmc/60/12/60_ra.2020-0197/_article (visitado 10-05-2022).
[12] V. Meca Lallana y J. Vivancos Mora, “Fármacos antiepilépticos,” es, Gastroenterología y Hepatología Continuada, vol. 8, n.o 6, págs. 332-335, nov. de 2009, Publisher: Elsevier, issn: 1578-1550. doi: 10.1016/S1578-1550(09)73011-6. (https://doi.org/10.1016/S1578-1550(09)73011-6) dirección: https://www.elsevier.es/es-revista-gastroenterologia-hepatologia-continuada-8-articulo-farmacos-antiepilepticos-S1578155009730116 (https://www.elsevier.es/es-revista-gastroenterologia-hepatologia-continuada-8-articulo-farmacos-antiepilepticos-S1578155009730116) (visitado 10-05-2022).

[13] J. Carrizosa Moog y W. Cornejo Ochoa, “¿Qué es la epilepsia refractaria?” es, Iatreia, vol. 16, n.o 2, págs. 163-167, jun. de 2003, issn: 0121-0793. dirección: http://www.scielo.org.co/scielo.php?script=sci_abstract&pid=S0121-07932003000200005&lng=es&nrm=iso&tlng=es (http://www.scielo.org.co/scielo.php?script=sci_abstract&pid=S0121-07932003000200005&lng=es&nrm=iso&tlng=es) (visitado 10-05-2022).
[14] New treatment options for drug-resistant epilepsy, en. dirección: https://www.uchicagomedicine.org/forefront/neurosciences-articles/new-treatment-options-for-peoplewith-drug-resistant-epilepsy (https://www.uchicagomedicine.org/forefront/neurosciences-articles/new-treatment-options-for-people-with-drug-resistant-epilepsy) (visitado 10-05-2022).
[15] W. J. C. v. Elmpt, T. M. E. Nijsen, P. A. M. Griep y J. B. A. M. Arends, “A model
of heart rate changes to detect seizures in severe epilepsy,” Seizure, vol. 15, n.o 6, págs. 366-375, 2006, issn: 1059-1311. doi: https://doi.org/10.1016/j.seizure. 2006.03.005. (https://doi.org/https://doi.org/10.1016/j.seizure.2006.03.005) dirección: https://www.sciencedirect.com/science/article/pii/S1059131106000598. (https://www.sciencedirect.com/science/article/pii/S1059131106000598)

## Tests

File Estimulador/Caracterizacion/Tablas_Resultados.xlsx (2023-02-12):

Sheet: PWM
Frecuencia PWM Teórica (Hz) | Pomedio PWM (Hz) | Error (%) | Ciclo de trabajo teórico (%) | Ciclo de trabajo experimental (%) | Error ciclo de trabajo (%) | Ancho de pulso teorico (ms) | Promedio Ancho de pulso (ms) | Error ancho de pulso (%) | voltaje (v)
1 | 0.933 | 6.7% | 50.0% | 48.0% | 4.0% | 500.00 | 490 | 2.0% | 3.3
1 | 0.833 | 16.7% | 55.0% | 56.0% | 1.8% | 550.00 | 560 | 1.8% | 3.32
2 | 2.08 | 4.0% | 50.0% | 51.0% | 2.0% | 250.00 | 248 | 0.8% | 3.3
2 | 2.08 | 4.0% | 55.0% | 52.0% | 5.5% | 275.00 | 280 | 1.8% | 3.3
5 | 5 | 0.0% | 20.0% | 21.0% | 5.0% | 40.00 | 40 | 1.776356839e-14% | 3.28
5 | 5 | 0.0% | 50.0% | 48.0% | 4.0% | 100.00 | 100 | 0.0% | 3.3
5 | 5 | 0.0% | 55.0% | 53.0% | 3.6% | 110.00 | 113 | 2.7% | 3.3
10 | 10.4 | 4.0% | 20.0% | 21.0% | 5.0% | 20.00 | 19.4 | 3.0% | 3.3
10 | 10.4 | 4.0% | 50.0% | 48.0% | 4.0% | 50.00 | 49.6 | 0.8% | 3.31
10 | 10.4 | 4.0% | 55.0% | 52.0% | 5.5% | 55.00 | 55.2 | 0.4% | 3.31
15 | 16.7 | 11.3% | 20.0% | 23.0% | 15.0% | 13.33 | 12.8 | 4.0% | 3.26
15 | 14.6 | 2.7% | 50.0% | 47.0% | 6.0% | 33.33 | 33.6 | 0.8% | 3.26
15 | 14.6 | 2.7% | 55.0% | 57.0% | 3.6% | 36.67 | 36.8 | 0.4% | 3.3
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

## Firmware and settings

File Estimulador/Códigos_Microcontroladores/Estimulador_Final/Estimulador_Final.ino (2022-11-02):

 #include <SPI.h>

// ............................................. PWM and Timer Formulas ................................................

// PWM frequency:
// freq = GCLKx_freq/(TCCx_Prescaler*(1+TOP_Value))
// => Top_Value = (GCLKx_freq/TCCx_Prescaler*freq)-1

// Timer value:
// Time = (Timer_Presc*dfactor/GCLKx_freq)*(CCx+1)
// => CCx = time*(GCLKx_freq/Timer_Presc*dfactor)-1

// Note: dfactor is a scaling factor selected in clock divider to GCLKx configuration


// ....................................... PWM and Timer Values Data Base...............................................


// Frequency configuration of the Stimulation Signal (PWM) for 30, 25, 20, 15, 10, 5, 2 and 1Hz  
const unsigned int PWM_freq[3][8] = {{1562, 1874, 2343, 3124, 4687, 9374, 23437, 46874},    // 48MHz
                                     {1041, 1249, 1562, 2082, 3124, 6249, 15624, 31249},    // 8MHz
                                     {1066, 1279, 1599, 2132, 3199, 6399, 15999, 31999}};   // 32KHz

// CCx values for 1ms, 750us, 500us, 250us and 130us respectively, for pulse 
// width or hight state in the square signal (PWM) during the Stimulation Time
const unsigned char PWM_pw[3][5] = {{47, 35, 23, 12, 6},   // 48MHz
                                    {31, 23, 16, 8, 4},    // 8MHz
                                    {32, 24, 16, 8, 4}};   // 32KHz

// Array for CCx values for 600, 300, 180, 108, 66, 60 48, 30, 21, 18, 14, 7, 2, 1s respectively, for
// On/Off time for Stimulation Signal. Clock at 32KHz
const unsigned int ON_OFF_TIME[14] = {18749, 9374, 5624, 3374, 2062, 1874, 1499, 937, 655, 562, 437, 218, 62, 30};


// ........................................ PWM and Timer Values Selection .............................................


volatile unsigned int period;         // = PWM_freq[0][3];
volatile float pulse_width;           // = period*0.25; //PWM_pw[2][0];     
volatile int ON_Time;                 // = ON_OFF_TIME[13];
volatile int OFF_Time;                // = ON_OFF_TIME[13];


// ............................... Variables for PWM, Timer and Digital Potentiometer ..................................

bool flag = 0;
byte mode = 0;
byte pulsos = 0;
bool Ramp_mode = false; 
bool go_to_sleep = false;
bool update_mode = false;
bool Resume_Repose = false;
bool Magnet_Triggered = false;
bool magnet_mode = false;

uint8_t amplitude;
float output_voltage = 2.75;                        // Standard Mode Voltage Output - Voltage (V)
uint8_t frequency = 25;                              // Standard Mode Stimulation Frequency - Hertz (Hz)
uint16_t Stimulation_time = 2;                      // Standard Mode Stimulation Time - Seconds (s)
uint16_t Repose_time = 7;                          // Standard Mode Repose Time - Seconds (s)

float magnet_output_voltage = 0.25;                  // Magnet Mode Voltage Output (V)
uint16_t magnet_Stimulation_time = 1;               // Magnet Mode Stimulation Frequency - Hertz (Hz)
uint16_t Pause_Repose;                              // Store Repose Time to Resume After a Magnet Mode Stimulation

float ramp_interval;
int timer_interval;
int amplitude_max;                                  // Maximum Stimulation Amplitude (V)
int amplitude_min = 1;                              // Minimum Stimulation Amplitude (V)
 
uint16_t pot_command;
uint16_t pot_value;


// .....................................................................................................................


void setup()
{

  //PM->CPUSEL.reg = PM_CPUSEL_CPUDIV(2);

//...................................... Set Input/Output Pins Mode Configuration ......................................

  SPI.begin();                                                            // Enable SPI Communication
  
  pinMode(0, OUTPUT);                                                     // VNS Stimulation Signal Output 
  pinMode(1, INPUT_PULLUP);                                               // Input for Hall Sensor (open drain)
  PORT->Group[PORTA].DIRSET.reg = PORT_PA10;                              // Set PA03 Pin as Output (CS SPI Communication)
  PORT->Group[PORTA].OUTSET.reg = PORT_PA10;                              // Set PA03 Pin to High
  attachInterrupt(digitalPinToInterrupt(1), Hall_Sensor_ON, RISING);      // Configure Rising Interrupt for Hall Sensor
    
// .....................................................................................................................

  amplitude_max = output_voltage*(255/3.3)+4;
  
  switch (frequency) 
  { 
    case 1:
      period = PWM_freq[1][7];    
      break;
    case 2:
      period = PWM_freq[1][6];
      break;       
    case 5:
      period = PWM_freq[1][5];
      break;       
    case 10:
      period = PWM_freq[1][4];
      break;
    case 15:
      period = PWM_freq[1][3];
      break;
    case 20:
      period = PWM_freq[1][2];
      break;
    case 25:
      period = PWM_freq[1][1];
      break; 
    case 30:
      period = PWM_freq[1][0];
      break;                                           
    default:
      period = PWM_freq[1][7];
      break;
  }

  //pulse_width = PWM_pw[1][4];
  pulse_width = period*0.5;

  switch (Stimulation_time) 
  { 
    case 1:
      ON_Time = ON_OFF_TIME[13];    
      break;
    case 2:
      ON_Time = ON_OFF_TIME[12]; 
      break;       
    case 7:
      ON_Time = ON_OFF_TIME[11]; 
      break;       
    case 14:
      ON_Time = ON_OFF_TIME[10]; 
      break;
    case 18:
      ON_Time = ON_OFF_TIME[9]; 
      break;
    case 21:
      ON_Time = ON_OFF_TIME[8]; 
      break;
    case 30:
      ON_Time = ON_OFF_TIME[7]; 
      break; 
    case 48:
      ON_Time = ON_OFF_TIME[6]; 
      break;    
    case 60:
      ON_Time = ON_OFF_TIME[5]; 
      break;                 
    case 66:
      ON_Time = ON_OFF_TIME[4]; 
      break; 
    case 108:
      ON_Time = ON_OFF_TIME[3]; 
      break;     
    case 180:
      ON_Time = ON_OFF_TIME[2]; 
      break;
    case 300:
      ON_Time = ON_OFF_TIME[1]; 
      break;          
    case 600:
      ON_Time = ON_OFF_TIME[0]; 
      break;     
    default:
      ON_Time = ON_OFF_TIME[7];
      break;
  }


  switch (Repose_time) 
  { 
    case 1:
      OFF_Time = ON_OFF_TIME[13];    
      break;
    case 2:
      OFF_Time = ON_OFF_TIME[12]; 
      break;       
    case 7:
      OFF_Time = ON_OFF_TIME[11]; 
      break;       
    case 14:
      OFF_Time = ON_OFF_TIME[10]; 
      break;
    case 18:
      OFF_Time = ON_OFF_TIME[9]; 
      break;
    case 21:
      OFF_Time = ON_OFF_TIME[8]; 
      break;
    case 30:
      OFF_Time = ON_OFF_TIME[7]; 
      break; 
    case 48:
      OFF_Time = ON_OFF_TIME[6]; 
      break;    
    case 60:
      OFF_Time = ON_OFF_TIME[5]; 
      break;                 
    case 66:
      OFF_Time = ON_OFF_TIME[4]; 
      break; 
    case 108:
      OFF_Time = ON_OFF_TIME[3]; 
      break;     
    case 180:
      OFF_Time = ON_OFF_TIME[2]; 
      break;
    case 300:
      OFF_Time = ON_OFF_TIME[1]; 
      break;          
    case 600:
      OFF_Time = ON_OFF_TIME[0]; 
      break;     
    default:
      OFF_Time = ON_OFF_TIME[0];
      break;
  }

  if (frequency >= 10) Ramp_mode = true; 
  else Ramp_mode = false;  

  
//...................................... Configurate PWM (Stimulation signal) ..........................................

  PWM_Config();
  Enable_PWM_Interrupts();  
  
// ......................... CONFIGURAR TIEMPO DE ACTUALIZACIÓN DE LA RAMPA ............................................

if (Ramp_mode)
{
  ramp_update();                                  // Calculate Ramp Time Update
  Timer2_Config();                                // Configurate Timer for Ramp Amplitude Refresh
  Timer2_Interrupts();                            // Enable Ramp Amplitude Refresh
  Timer2_Start();                                 // Start Timer for Ramp Amplitude Refresh
}
else
{
  amplitude = amplitude_max;
}

//...................................... Configurar Timer (ON/OFF Time) ................................................

  Timer_Config();           
  Timer_Start();   
  flag = true;

}



void loop() 
{


  if(magnet_mode)
  {
    Hall_Sensor(); 
    magnet_mode = false; 
  }

  if(update_mode)
  {
    next_mode();
    update_mode = false;  
  }

  if(flag)
  {
    setResistance(amplitude);     
    flag = false;
  }

  if(go_to_sleep)
  {
    go_to_sleep = false;
    SAMD21_Sleep();    
  }

  
}


// ............................. HALL Sensor Activation for On Demand Mode .............................................


void Hall_Sensor_ON()
{
  magnet_mode = true;  
}


// ............................. HALL Sensor Activation for On Demand Mode .............................................


void Hall_Sensor()
{

  if(mode == 4) 
  {
    Pause_Repose = TC5->COUNT16.COUNT.reg;
    Resume_Repose = true; 
  }

  mode = 0;
  flag = 0;
  pulsos = 0;
  go_to_sleep = false;
  Magnet_Triggered = true; 

  // Amplitude Change to Magnet Mode Parameters
  Timer2_Stop();
  amplitude_max = magnet_output_voltage*(255/3.3)+4;        // Calculate Magnet Mode Amplitude
  if(Ramp_mode) amplitude = amplitude_min;                  // Select Initial Amplitude (with or without ramp mode)
  else amplitude = amplitude_max;                       
  ramp_update();                                            // Calculate Ramp Time Update
  Timer2_Config();                                          // Configurate Timer for Ramp Amplitude Refresh   
  
  flag = true;
  update_mode = true;
  
}


// ............................. TIMER DE ACTUALIZACIÓN DE AMPLITUD DE LA RAMPA ........................................


void TCC0_Handler()
{

  if(mode==2)                                 // ¿Intevalo de Estimulación?
  {
    pulsos++;                                 // Contar pulsos realizados
    
    if(pulsos == frequency)                   // ¿# de pulsos coinciden con la frecuencia configurada?
    {
      pulsos=0;                               // Reiniciar contador de pulsos
      if(Ramp_mode) amplitude--;              // Disminuir en -1 la amplitud para entrar en rampa de bajada
      flag = true;                            // Actualizar amplitud del poteciometro
    } 
     
  }

  TCC0->INTFLAG.bit.MC0 = 1;                  // Clear interrupt flag
  
}


// ............................. TIMER PARA GENERAR SEÑAL PWM DE ESTIMULACIÓN ..........................................


void TCC1_Handler()
{

  if(mode==1) amplitude++;                      // ¿Rampa de subida? -> Incrementar Amplitud 
  else if(mode==3) amplitude--;                 // ¿Rampa de bajada? -> Decrementar Amplitud

  if(amplitude > amplitude_max) amplitude = amplitude_max;  
  if(amplitude < amplitude_min) amplitude = amplitude_min;
  
  flag = 1;
  TCC1->INTFLAG.bit.MC0 = 1;            
  
}


// .....................................................................................................................


void setResistance(int percent)
{
   
  pot_command = 0x0011;                                             // Write Command to Potentiometer
  pot_value = (pot_command << 8) | percent;                         // Add Potentiometer Value to Write Command

  PORT->Group[PORTA].OUTCLR.reg = PORT_PA10;                        // Set Potentiometer CS Pin to Low
  delayMicroseconds(50);                                            // Delay
  
  SPI.beginTransaction(SPISettings(1000000, MSBFIRST, SPI_MODE0));  // Begin SPI Transaction  
  SPI.transfer16(pot_value);                                        // Write New Value to Potentiometer
  SPI.endTransaction();                                             // End SPI Transaction
  
  delayMicroseconds(50);                                            // Delay
  PORT->Group[PORTA].OUTSET.reg = PORT_PA10;                        // Set Potentiometer CS Pin to High

}


// .....................................................................................................................


void TC5_Handler (void) 
{

  update_mode = true;
  TC5->COUNT16.INTFLAG.bit.MC0 = 1;                     // Clear interrupt flag  
  
}


// .....................................................................................................................


void next_mode(void)
{
  
  if(Ramp_mode)                                         // Ramp Mode On?
  {                                                     // Ramp Mode On (Freq. >= 10):
    mode++;                                             // Use Sequence: Ramp Up -> On Time -> Ramp Down -> Off Time
    if(mode>=5) mode=1;                                 // Reset Stimultation Sequence    
  }
  else                                                  
  {                                                     // Ramp Mode Off (Freq. < 10):
    if(mode==2) mode = 4;                               // Use Sequence: On Time -> Off Time
    else mode = 2;                                      // Reset Stimultation Sequence 
  } 

  
  if(mode == 1)                                         // Ramp Up Interval Active?
  {    
    Timer_Disable();                                    // Stop Timer to change to Ramp Up Time (2s)
    TC5->COUNT16.CC[0].reg = (uint16_t) 62;             // Set TC5 value with Ramp Up Time (2s)   
    PWM_Start();                                        // Start PWM  (Stimulation Signal)
    Timer_Start();                                      // Enable Timer again    
    Timer2_Start();                                     // Update Up Ramp Amplitude Interval    
  }
  else if(mode == 2)                                    // On Time Interval Active?
  {
    Timer2_Stop();                                      // Stop Update of Ramp Amplitude 
    pulsos=0;                                           // Reset Stimulation Pulses Count
    Timer_Disable();                                    // Stop Timer to change to ON time value   
    TC5->COUNT16.CC[0].reg = (uint16_t) ON_Time;        // Set TC5 value with ON Time (Stimulation)    
    if(Ramp_mode == false) PWM_Start();                 // Enable PWM 
    Timer_Start();                                      // Enable Timer again    
  } 
  else if(mode == 3)                                    // Down Up Interval Active?
  {    
    Timer_Disable();                                    // Stop Timer to change to Ramp Down Time
    TC5->COUNT16.CC[0].reg = (uint16_t) 62;             // Set TC5 value with Ramp Down Time    
    Timer_Start();                                      // Enable Timer again     
    Timer2_Start();                                     // Update Down Ramp Amplitude                  
  }
  else if(mode == 4)                                    // Off Time Interval Active?
  {
    Timer2_Stop();                                      // Stop Update of Ramp Amplitude   
    PWM_Stop();                                         // Disable PWM     
    Timer_Disable();                                    // Stop Timer to change to OFF Time Value
    TC5->COUNT16.CC[0].reg = (uint16_t) OFF_Time;       // Set TC5 value with OFF Time (Repose)
    
    if (Resume_Repose) 
    {
      TC5->COUNT16.COUNT.reg = Pause_Repose;
      Resume_Repose = false;
    }    

    if(Magnet_Triggered)
    {   
      amplitude_max = output_voltage*(255/3.3)+4;
      if(Ramp_mode) amplitude = amplitude_min;
      else amplitude = amplitude_max;
      ramp_update();                                            // Calculate Ramp Time Update
      Timer2_Config();                                          // Configurate Timer for Ramp Amplitude Refresh  
      Magnet_Triggered = false; 
    }
    
    Timer_Start();                                      // Enable Timer again        
    //go_to_sleep = true;                                 // Enter in Standy Mode to Save Energy
  }
    
}


// .....................................................................................................................


void ramp_update()
{

  // CCx = (time*(8MHz/1024))-1
  // 1/time = (amplitude_max-1)/2000ms   
   
  amplitude = amplitude_min;                      // Ramp-up Starts in Amplitude = 1
  ramp_interval = (amplitude_max-1)/2;            // (98-1)/2s = 48.5Hz => 20.62ms
  timer_interval = (7812.5/ramp_interval)-1;      // (7812.5/ramp_interval)-1;     // (46,875.0/48.5)-1 = 965.49 => 965 

}


// .....................................................................................................................


void PWM_Config()
{

  PM->APBCMASK.reg |= PM_APBCMASK_TCC0;
  //GCLK_GENCTRL_RUNSTDBY |             // Set GCLK4 to run in standby mode 


  // Enable and configure the Generic CLK Generator (GCLK)
  GCLK->GENCTRL.reg = GCLK_GENCTRL_IDC |                  // Improve duty cycle 
                      GCLK_GENCTRL_GENEN |                // Enable GCLK
                      GCLK_GENCTRL_SRC_OSC8M |            // OSC32K | OSC8M | DFLL48M |   // Set the 8MHz as Clock Source
                      GCLK_GENCTRL_ID(4);                 // Select GCLK4 as ID 
  while (GCLK->STATUS.bit.SYNCBUSY);                      // Wait for synchronization


  // Select clock divider to GCLK4
  GCLK->GENDIV.reg = GCLK_GENDIV_DIV(1) |                 // Divide 8MHz by 1 
                     GCLK_GENDIV_ID(4);                   // Apply it to GCLK4    
  while (GCLK->STATUS.bit.SYNCBUSY);                      // Wait for synchronization

  
  // Enable GCLK4 and connect it to TCC0 and TCC1
  GCLK->CLKCTRL.reg = GCLK_CLKCTRL_CLKEN |                // Enable Generic Clock 
                      GCLK_CLKCTRL_GEN_GCLK4 |            // Select GCLK4
                      GCLK_CLKCTRL_ID_TCC0_TCC1;          // Feed CLK4 to TCC0 and TCC1
  while (GCLK->STATUS.bit.SYNCBUSY);                      // Wait for synchronization


  TCC0->CTRLA.reg |= TCC_CTRLA_PRESCALER_DIV256;          // Divide counter by 1 (This is N)
  TCC0->CTRLA.reg |= TC_CTRLA_MODE_COUNT16;               // Set Timer counter Mode to 16 bits
  TCC0->WAVE.reg = TCC_WAVE_WAVEGEN_NPWM;                 // Select NPWM (Single-slope): count up to PER, match on CC[n]
  while (TCC0->SYNCBUSY.bit.WAVE);                        // Wait for synchronization

  TCC0->PER.reg = period;                                 // Set the period (TOP) for rate or frequency of PWM signal
  while (TCC0->SYNCBUSY.bit.PER);                         // Wait for synchronization

  // Set duty cycle where n for CC[n] is n = x % 4 and x is form WO[x]
  TCC0->CC[0].reg = pulse_width;                          // Set PWM signal to 50% of duty cicle 
  while (TCC0->SYNCBUSY.bit.CC0);                         // Wait for synchronization

  // Configure PA08 (D0 in Trinket) to be output
  PORT->Group[PORTA].DIRSET.reg = PORT_PA08;              // Set pin as output
  PORT->Group[PORTA].OUTCLR.reg = PORT_PA08;              // Set pin to low
  PORT->Group[PORTA].PINCFG[8].reg |= PORT_PINCFG_PMUXEN; // Enable the port multiplexer for PA08

  // Connet TCC1 timer to PA08. Function F is TCC1/WO[2] for PA08. Function E is TCC0/WO[0]
  // Odd pin num (2*n+1): use PMUXO
  // Even pin num (2*n): use PMUXE
  PORT->Group[PORTA].PMUX[4].reg = PORT_PMUX_PMUXE_E;
  
}


// .....................................................................................................................


void Enable_PWM_Interrupts(void)
{
  // Configure interrupt request
  NVIC_DisableIRQ(TCC0_IRQn);                           // Deshabilitar interrupciones
  NVIC_ClearPendingIRQ(TCC0_IRQn);                      // Limpiar banderas de interrupción
  NVIC_SetPriority(TCC0_IRQn, 0);                       // Nivel de prioridad de la interrupción
  NVIC_EnableIRQ(TCC0_IRQn);                            // Habilitar interrupciones
  
  TCC0->INTENSET.bit.MC0 = 1;                           // Enable TC5 Overflow Interrupt Request (OVF)
  while(TCC0->STATUS.reg & TC_STATUS_SYNCBUSY); 
}


// .....................................................................................................................


void PWM_Start()
{ 
  TCC0->CTRLA.reg |= (TCC_CTRLA_ENABLE);                // Enable TCC1 (Start PWM)
  while (TCC0->SYNCBUSY.bit.ENABLE);                    // Wait for synchronization     
}


// .....................................................................................................................


void PWM_Stop()
{
  TCC0->CTRLA.reg &= (~TCC_CTRLA_ENABLE);               // Disable TCC1 (Stop PWM)
  while (TCC0->SYNCBUSY.bit.ENABLE);                    // Wait for synchronization
}


// .....................................................................................................................
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

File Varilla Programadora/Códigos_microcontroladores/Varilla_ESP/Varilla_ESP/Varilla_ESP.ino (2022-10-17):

#include <ESP8266WiFi.h> // Librería para WiFi con ESP8266
#include <WiFiClient.h> // Librería para poder usar ESP8266 como cliente con protocolo TCP
#include <LiquidCrystal_I2C.h> // Librería para poder utilizar la LCD I2C
#include <Wire.h> // Librería que permite la comunicación con dispositivos I2C
#include <SPI.h> // Librería para comunicarse por SPI
#include <nRF24L01.h> // Librería específica del módulo RF
#include <RF24.h> // Librería para uso del módulo RF

/**************************** MODIFICAR CON LOS DATOS DE LA RED ***************************/
const char* ssid = "Galaxy_Note9";
const char* password = "hola12345"; //2PM7H7601455
/******************************************************************************************/

/*************************************** NO MODIFICAR *************************************/
char dato, dato2, dato3, dato4, dato5; // Variables tipo char en las que se almacenan las lecturas de los parámetros por WiFi
//int modo, ancho, tiempo, freq, sleep; // Variables tipo int para almacenar los parámetros a enviar por RF
int mssg = 0; // Variable tipo int en la que se va almacenando la lectura del puerto serial
int cond1, cond2, cond3, cond4, cond5 = 0; // Condiciones para cambio de parámetro en la comunicación serial
byte modop[1]; // MODIFICAR A CORRIENTE // Bytes para RF
byte anctime[2];
byte freqsleep[2];

int wifiFlag = 0; // Bandera que indica si el ESP8266 se pudo conectar a la red WiFi
int cont = 0; // Contador de parámetros para la comunicación por WiFi

RF24 radio(0, 2); // Se instancia el módulo RF. CE = D2, CSN = D4

const byte addresses[][6] = {"00001", "00002"}; // Direcciones de escritura y lectura. Pensar en ellos más como canales que "nombre" del dispositivo

uint8_t dataBus[6]; // Bus de parámetros
uint8_t dataConf[2]; // Bus de confirmación

LiquidCrystal_I2C lcd(0x27, 16, 2); // Se declara la pantalla LCD con dirección 0x27, 16 columnas y 2 filas

WiFiServer servidorTCP(8266); // Declaración del puerto en el que se encuentra el Servidor
WiFiClient clienteTCP; // Declaración del nombre del cliente TCP


void setup() {
  //-------------------------------------Serial------------------------------------------------
  Serial.begin(115200); // Se inicializa la comunicación serial a una tasa de 115200
  while (!Serial);     // Se espera a ésta se haya terminado de inicializar
  //----------------------------------- initialize LCD------------------------------------------
  lcd.init();     // Inicia LCD
  lcd.backlight();// Turn on LCD backlight
  lcd.home();     // Se inicia escribiendo en (0,0)
  lcd.clear();    // Se borra pantalla para que inicie limpia


  //----------------------------------Conexion Wifi------------------------------------------------
  WiFi.begin(ssid, password); // Se intenta conectar a la red WiFi establecida

  for (int k = 0; k < 20; k++) // Se intenta conectar a la red cada 200 ms, 20 veces
  { // La conexión a la red no es rápida, por lo que se debe dar varios intentos antes de declarar que la conexión no fue exitosa
    if (WiFi.status() != WL_CONNECTED) // Si no está conectado a WiFi
    {
      delay(500); // Volver a intentarlo cada 200 ms
    }
  }

  // Luego de los 20 intentos, se revisa si la conexión fue exitosa por última vez
  if (WiFi.status() != WL_CONNECTED) // Si no lo fue
  {
    wifiFlag = 0; // Bandera de WiFi apagada

    //Serial.println("No se pudo conectar a la red"); // Se indica en el monitor serial que no fue exitosa la conexión
    //Serial.println("Conectar cable USB a la computadora");

    lcd.print("Conex. WiFi:"); // Se muestra en la pantalla LCD que no se pudo conectar a la red
    lcd.setCursor(0, 1);
    lcd.print("No exitosa");
  }

  else // Si la conexión fue exitosa
  {
    wifiFlag = 1; // Bandera de WiFi encendida

    //Serial.print("Conectado, IP: "); // Se indica que la conexión fue exitosa
    Serial.println(WiFi.localIP()); // Se muestra la IP del NodeMcu
    //Serial.println("");


    // Se muestra estado de conexión en pantalla LCD
    lcd.print("Conex. WiFi:");
    lcd.setCursor(0, 1);
    lcd.print("Exitosa");
    // Después de 3 segundos
    delay(3000);
    lcd.clear();
    // Se muestra la IP de la varilla programadora
    lcd.print("IP: ");
    lcd.setCursor(0, 1);
    lcd.print(WiFi.localIP()); // Se muestra la IP en la pantalla LCD

    servidorTCP.begin(); // Se inicializa el servidor TCP
  }
  //-----------------------------------Modulo de RF------------------------------------------------
  radio.begin(); // Se inicializa el módulo RF
  radio.setAutoAck(1); // Se asegura que el auto ACK esté activo
  radio.setChannel(110); // Se declara el canal de uso, 2510 MHz
  radio.openWritingPipe(addresses[1]); // Dirección 1 para escribir
  radio.openReadingPipe(1, addresses[0]); // Dirección 0 para leer
  radio.setDataRate(RF24_250KBPS); // Tasa de datos de 250 kbs
  radio.setPALevel(RF24_PA_MIN); // PA power al mínimo, -18 dBm
}
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

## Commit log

2022-07-15 Importe de archivos csv
2022-08-04 RR_function
    Se agrega más ECG´s para muestra y se mejora el código
    [data.csv, data10.csv, data2.csv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]
2022-08-15 Poincare + primera revision
    [ECG_12h.csv, ECG_1h.csv, SampleReport.csv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]
2022-08-18 Cambio de nombre
2022-08-22 Envio de datos linea por linea
2022-09-27 PyHRV actualizado
    [SampleReport.csv]
2022-10-17 Códigos de trinkets
    [Varilla_programadora.PrjPcb]
2022-10-17 Libreria pyhton/ PyHRV modificado
    [data.csv, heart_disease_data.csv]
2022-10-17 Envio y recepción de parámetros
    Envio de parámetros a través de ESP8266
    Recepción de parámetros a través de Trinket M0
2022-10-31 Lista en python
    [Probabilidades.xlsx]
2022-11-20 Seccianado por estimulador y varilla programadora
    [Varilla_programadora.PrjPcb]
2022-11-20 Modo auto
    [DATOS_NUEVOS.csv, ECG_12h.csv, ECG_1h.csv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]
2022-11-20 Links a PCBs
2022-11-21 Instalacion de Trinket M0
2022-11-24 Detecta cada intervalo de tiempo
2022-11-25 Actualiza la gráfica del butterworh
2022-11-25 Graficas de picos actualizdas cada x tiempo
2022-11-25 Crea el resto de graficas
2023-01-05 Datos obtenidos caracterizacion
    [Tablas_Resultados.xlsx]
2023-01-05 Codigo Mejorado POT digtal
    [Tablas_Resultados.xlsx]
2023-01-05 Tablas de rampas
    [Tablas_Resultados.xlsx]
2023-01-06 gráficos
    [Tablas_Resultados.xlsx]
2023-01-06 Caracterización completa
    [Tablas_Resultados.xlsx]
2023-01-06 Duracion de bateria
    [Tablas_Resultados.xlsx]
2023-02-12 Modo automático y esquemas
    [LCD_Trinket_NRF24L01.fzz, Tablas_Resultados.xlsx, TrinketM0_NRF24L01.fzz]
2023-02-12 Esquemas y modo automático
    [Ejer1.csv, Ejer1_prueba.csv, Ejer2.csv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]
2023-02-13 Codigo de caracterización
